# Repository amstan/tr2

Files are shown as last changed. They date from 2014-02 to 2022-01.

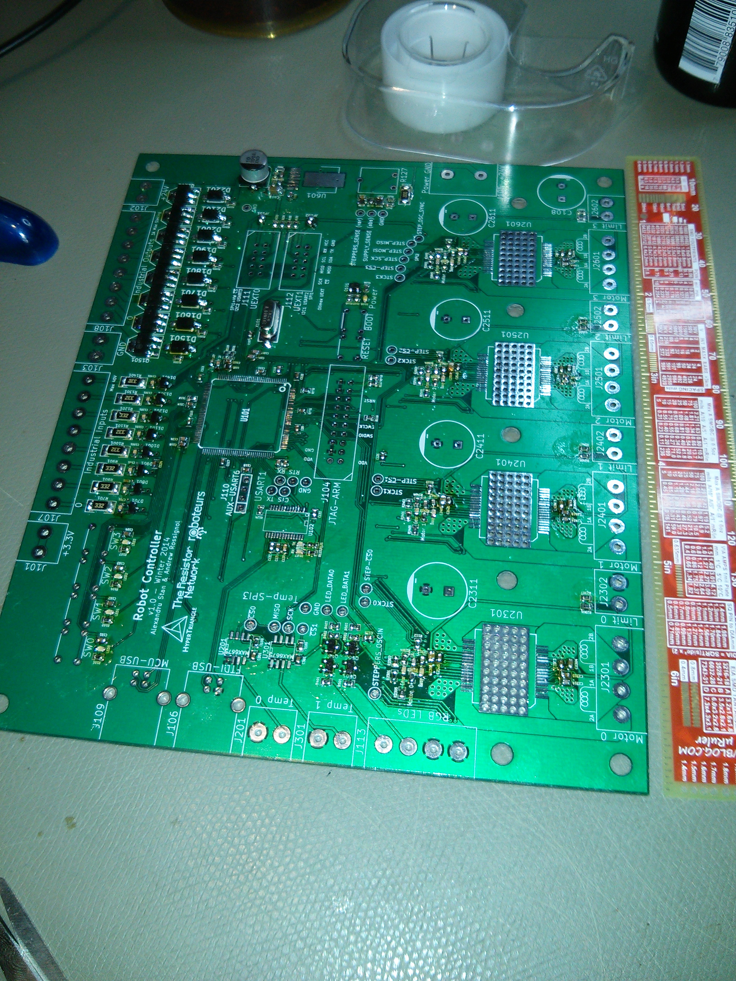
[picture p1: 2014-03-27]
pictures/board/partially assembled.jpg

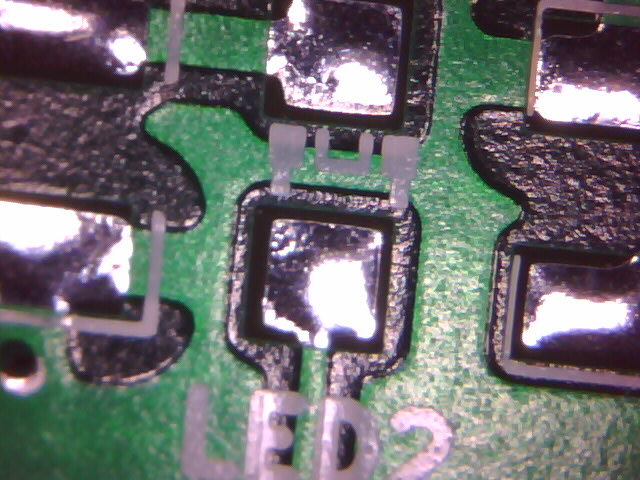
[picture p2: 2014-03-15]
pictures/board/microscope-prefab-8.jpg

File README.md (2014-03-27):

# tr2

## Overview

The goal of this project is to develop a hardware and accompanying software
platform for controlling robots from a high level programming language such as
Python.

## Hardware

The hardware will consist of a multi-axis motor control board, industrial
strength GPIO for controlling alarms, incandescent lamps, driving fans and more.

## Software

The software will provide an abstract interface to the hardware platform. The
first robot that will be tailored to this project will be a 3-axis Delta Robot.

## Project Structure

Here is the folder structure for the project:

* blender/
    * 3D models of target robots
* board/
    * The first hardware platform for this project
* board/bomParser/
    * Some pretty untested code to do mass changes in schematics/BOMs
* datasheets/
    * Component datasheets
* doc/
    * Notes, logo
* firmware/
    * Bare metal bring up of STM32F4 and code for the robot controller
* pictures/
    * Various pictures of the project
* python/
    * The python software interfaces
* ui/
    * A user interface to all of this

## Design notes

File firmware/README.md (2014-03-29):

# STM32F4 Bare Metal Bring Up

## Overview

This folder contains the base files required for the STM32F4 MCU. This work was
done on an STM32F4DISCOVERY board.

## Prerequisites

You must install the arm-none-eabi toolchain. It is available from
[this PPA](https://launchpad.net/~terry.guo/+archive/gcc-arm-embedded) for
Ubuntu/Mint.

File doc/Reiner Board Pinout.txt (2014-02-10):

STK - SPI Clock
SDL - MOSI
SDO - MISO
CS  - CS
Gnd - Gnd
Rst - Pull Up

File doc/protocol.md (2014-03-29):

# Board Protocol Definition

## Overview

This document describes the protocol used for communicating with the tr2 robot
controller board.

The tr2 robot controller board is intended merely as an IO extension of a host
platform such as a Linux Desktop PC or another embedded system.

## Message Format

    [Message Class]
    [Message Type]
    [Message Parameters]
    [CRC]

### Message Class

* Format  : Enum
* Length  : 8-bits
* Type    : MessageClass_t;
* Summary : The class of the message being sent. Example: User LED Command,
            Motor Command, Temperature Sensor Command

### Message Type

* Format  : Enum
* Length  : 8-bits
* Type    : MessageType_t (depends on the message class)
* Summary : The type of the message for this message classification. Example:
            Class: User LED Command, Type: Enable User LED

### Message Parameters

* Format  : Binary
* Length  : Variable
* Type    : uint8_t[]
* Summary : Each message class has a different set of parameters. Refer to the
            sections below for more information.

### Message Error Checking

* Format  : Binary
* Length  : 16-bits
* Type    : uint16_t
* Summary : Error checking is the last two bytes of every message. Error
            checking is a simple sum of all bytes in the message. Big-endian or
            network order is used here.

## Message Classifications

All messages communicating to and from the tr2 robot controller board have an
associated message class to aid in protocol implementation.

### User LED

* Value : 0

This classification interacts with the user LEDs on the board.

#### Message Types

##### Enable LED

* Value  : 0
* Sender : Host

This command enables one of the user LEDs.

###### Parameters

* LED Index
    * Value  : 0 - 3
    * Length : 8-bits

###### Response

Acknowledge user LED command.

##### Disable LED

* Value  : 1
* Sender : Host

This command disables one of the user LEDs.

###### Parameters

* LED Index
    * Value  : 0 - 3
    * Length : 8-bits

###### Response

Acknowledge user LED command.

##### Toggle LED

* Value  : 2
* Sender : Host

This command toggles one of the user LEDs.

###### Parameters

* LED Index
    * Value  : 0 - 3
    * Length : 8-bits

###### Response

Acknowledge user LED command.

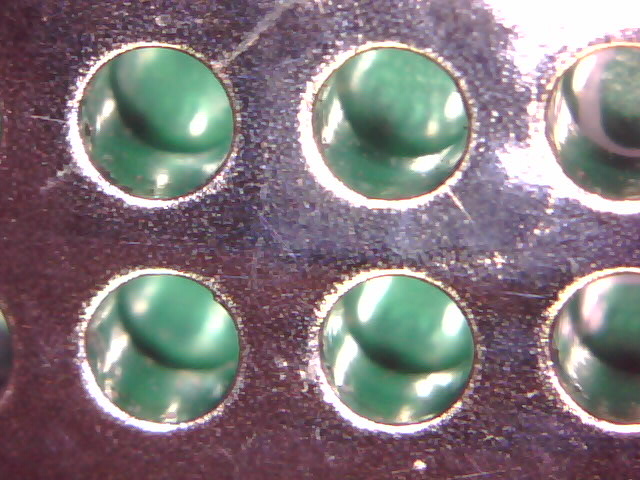
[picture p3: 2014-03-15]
pictures/board/microscope-prefab-5.jpg

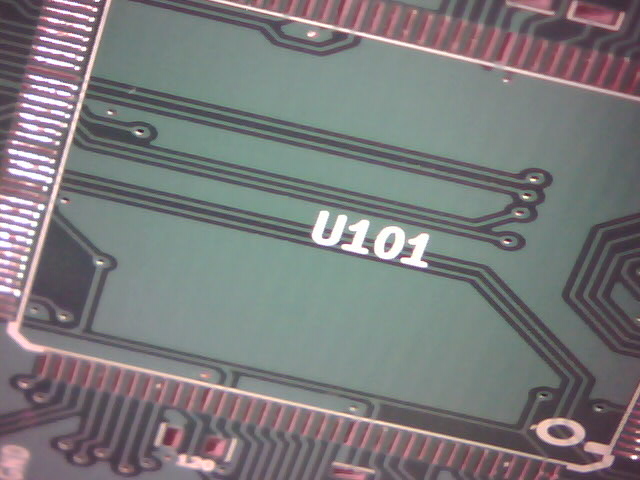
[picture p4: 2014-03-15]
pictures/board/microscope-prefab-10.jpg

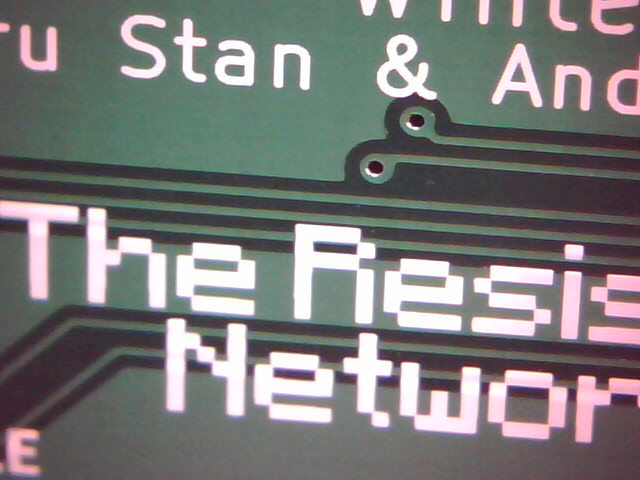
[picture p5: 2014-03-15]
pictures/board/microscope-prefab-11.jpg

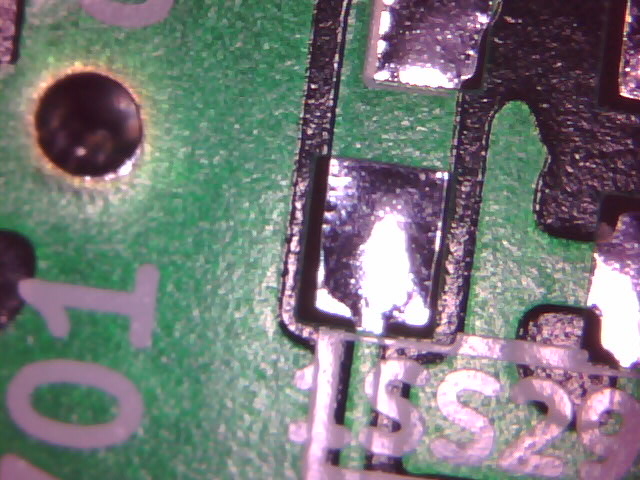
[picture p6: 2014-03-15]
pictures/board/microscope-prefab-9.jpg

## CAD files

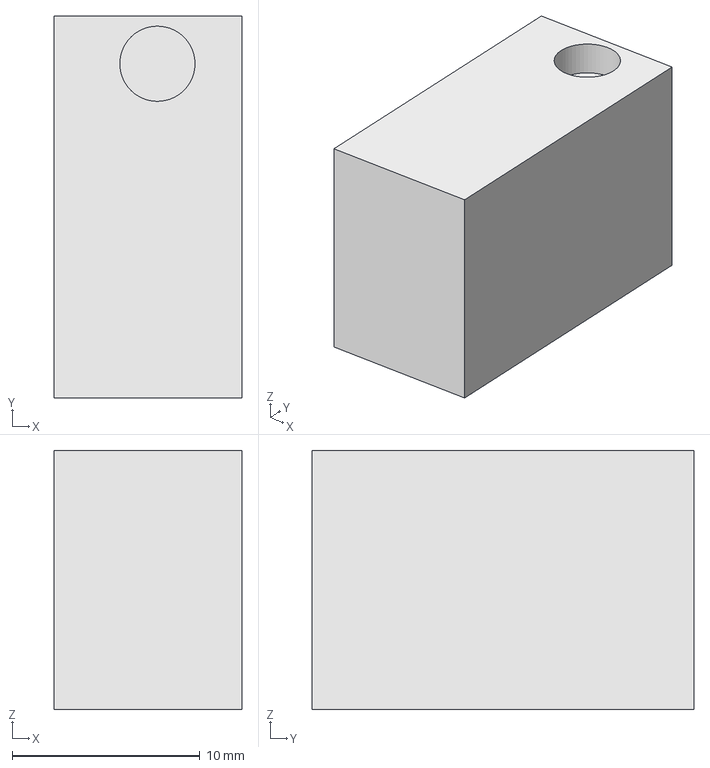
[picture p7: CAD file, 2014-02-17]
board/models/9993920000.fcstd
10.0 x 20.3 x 13.8 mm

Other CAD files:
blender/test_kinematics.blend

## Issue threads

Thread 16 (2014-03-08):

Fix connector names/values

amstan, 2014-03-08:
Kicad does not allow custom values for components from inside sheets(ex: Temp Probe connectors). I can change them inside the pcb, but every time i do another netlist import they get overwritten.

I need to name everything nicely just before the end.

Closed 2022-01-26.

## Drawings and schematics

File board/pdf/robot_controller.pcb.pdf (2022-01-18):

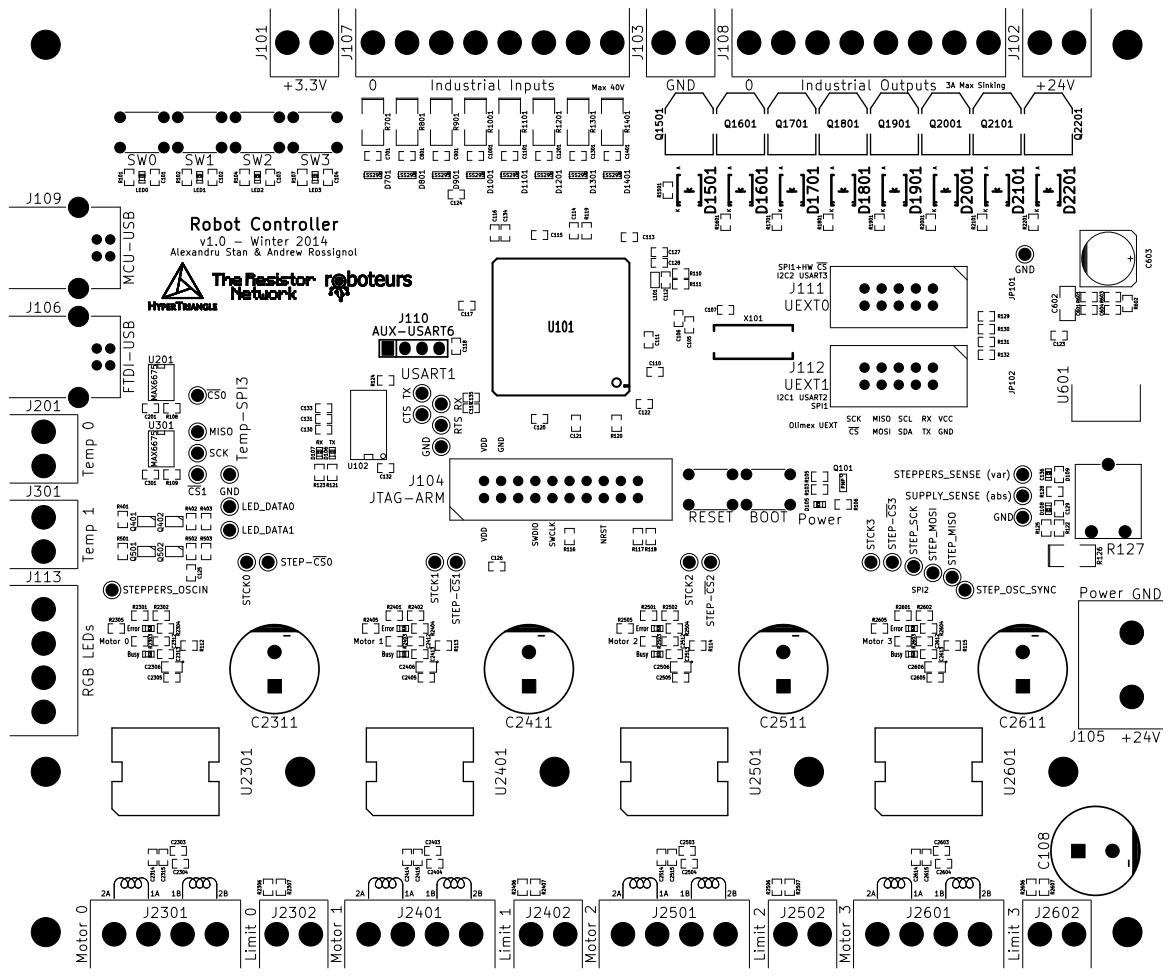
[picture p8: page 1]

Olimex UEXT Max 40V Robot Controller
J110 AUX-USART6 J2302 Limit 0

Alexandru Stan & Andrew Rossignol

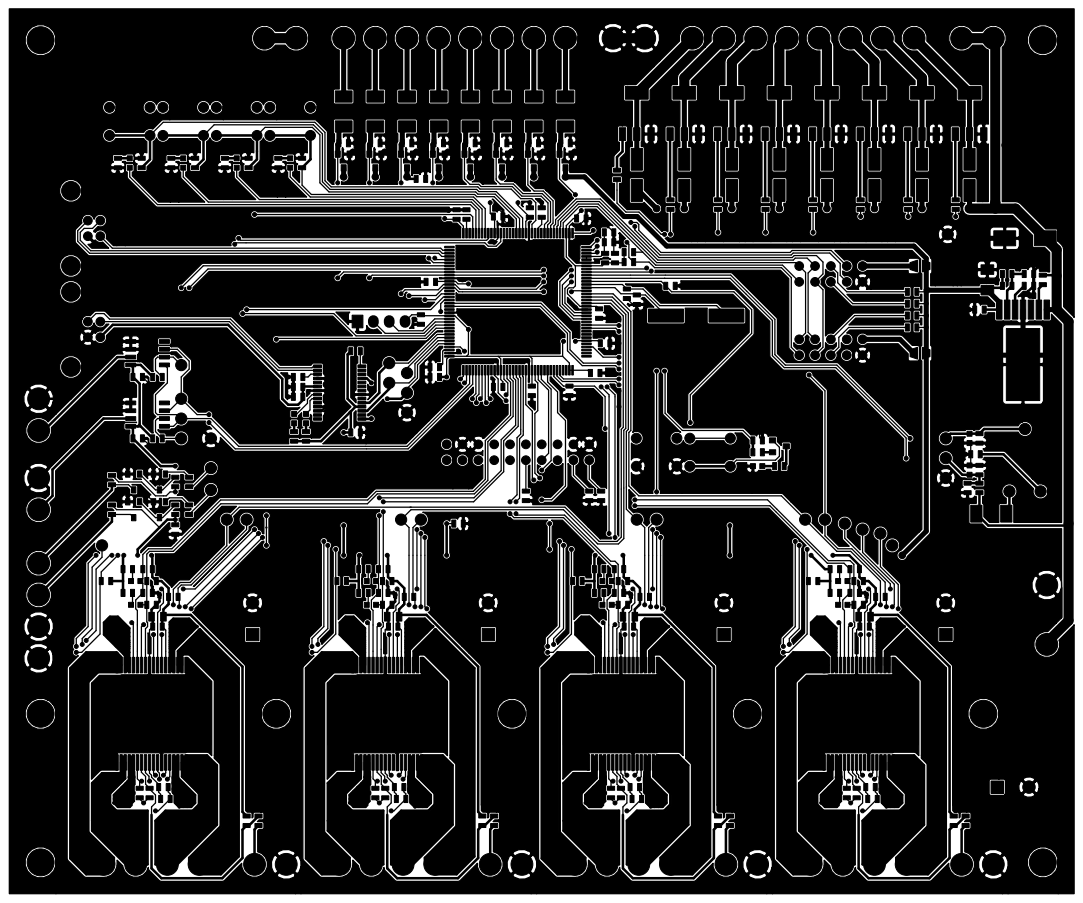
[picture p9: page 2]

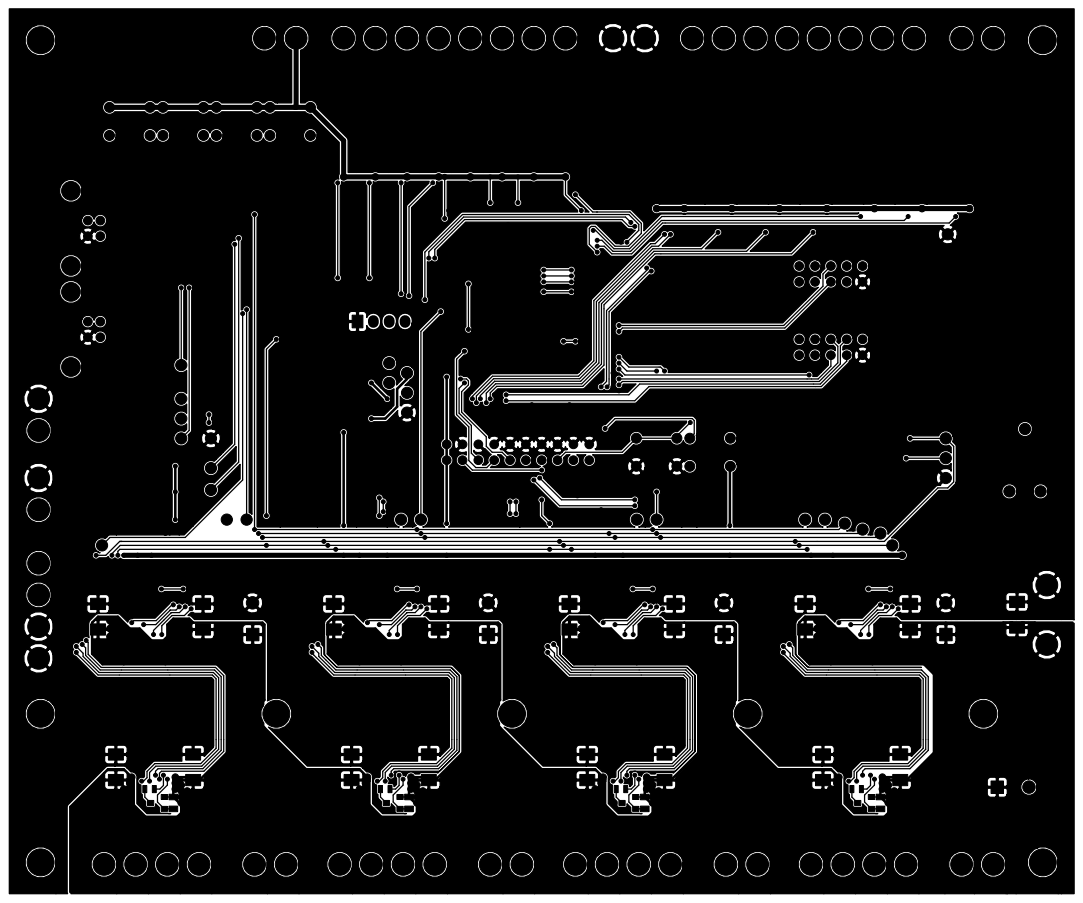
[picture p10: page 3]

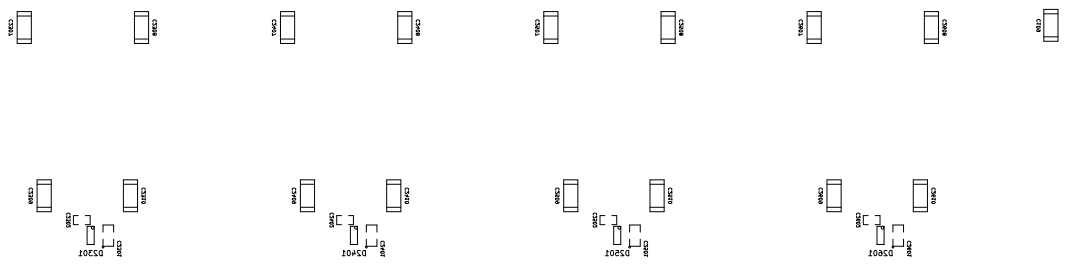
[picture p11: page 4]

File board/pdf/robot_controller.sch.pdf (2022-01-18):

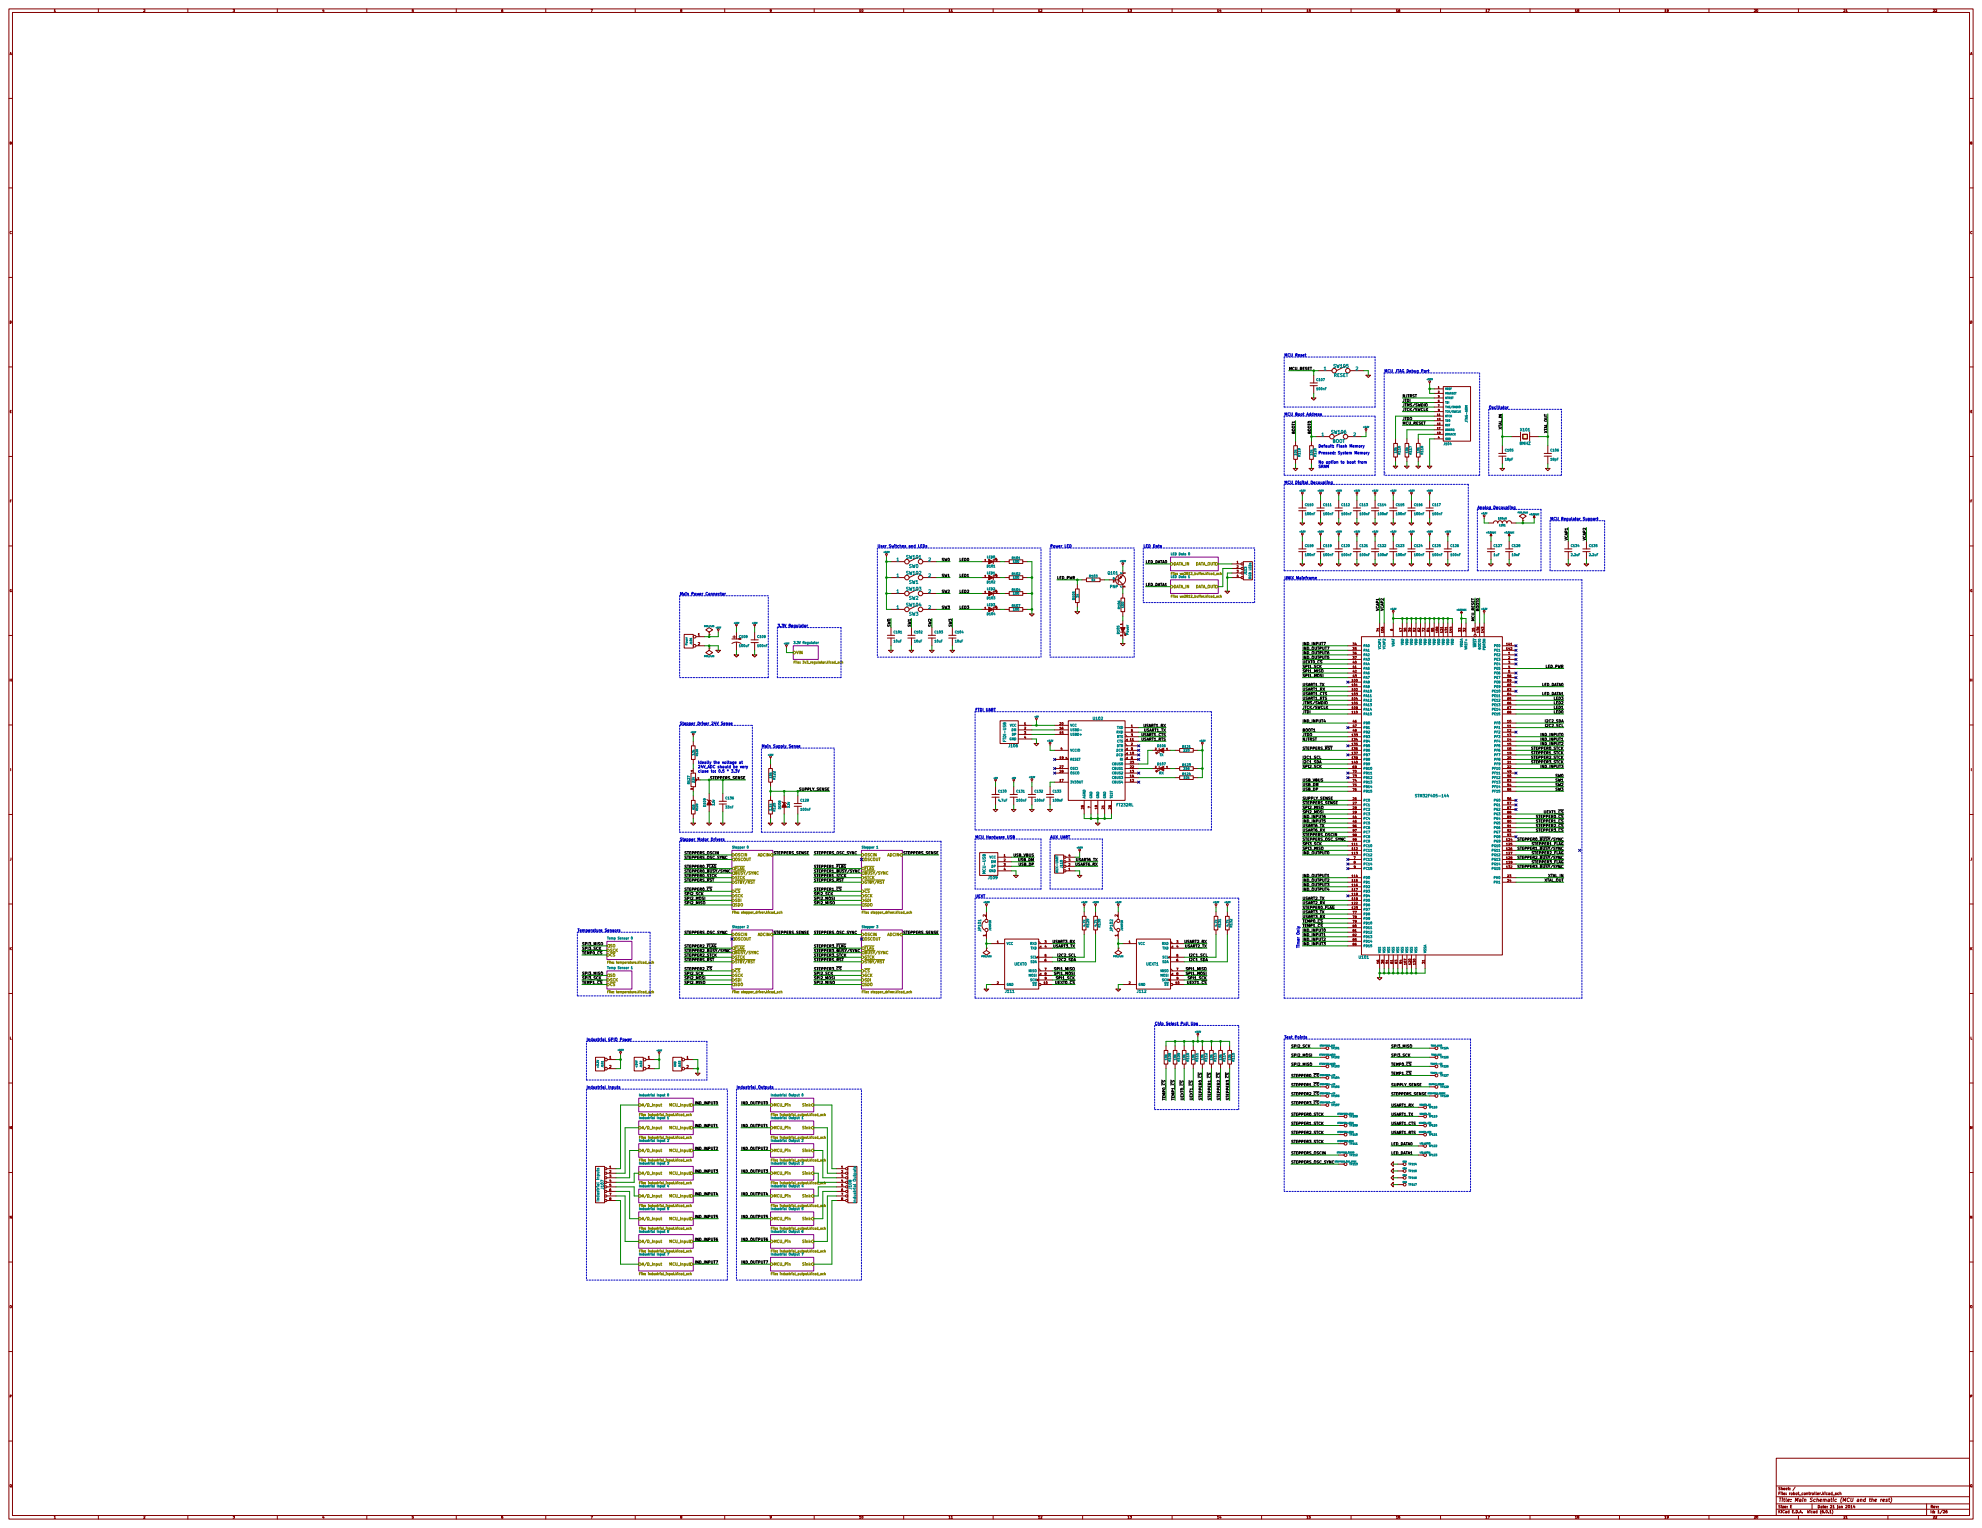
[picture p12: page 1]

MCU JTAG Debug Port Power LED

No option to boot from
SRAM

User Switches and LEDs
LED1 SW3

UNIX Mainframe Timer Only

Ideally the voltage at
24V_ADC should be very
close to: 0.5 * 3.3V
STEPPERS_SENSE

File: robot_controller.kicad_sch Sheet: /
Id: 1/26 Title: Main Schematic (MCU and the rest)

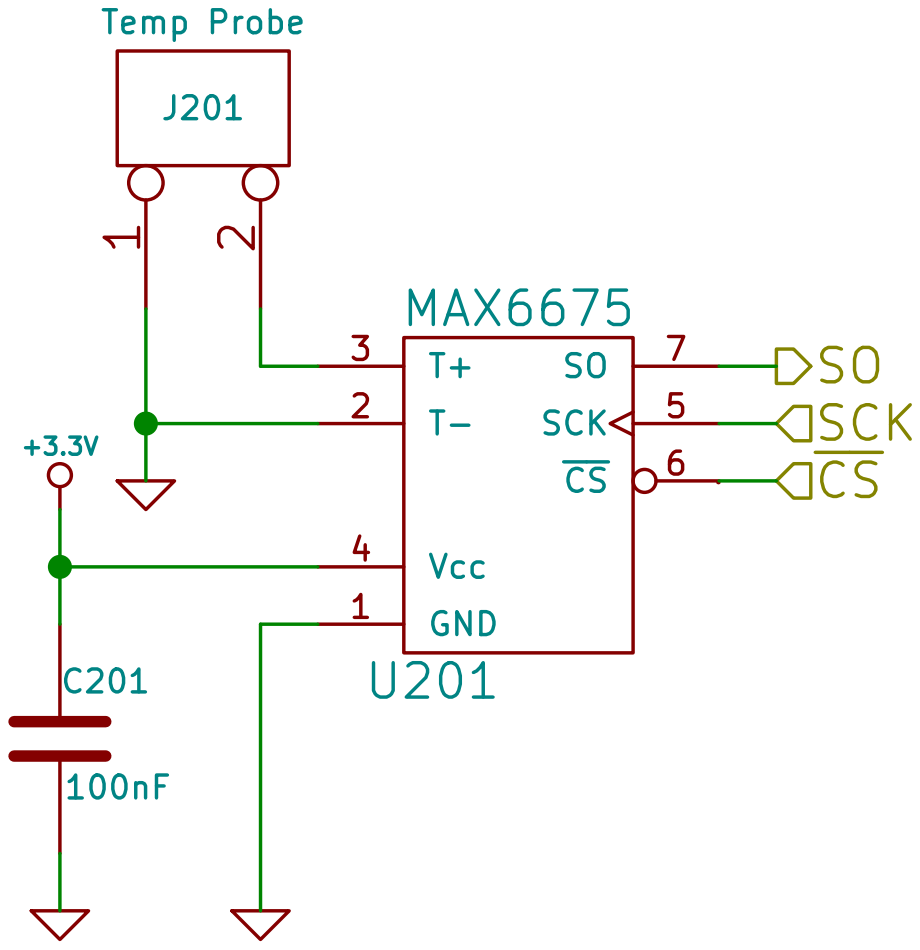
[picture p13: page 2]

Sheet: /Temp Sensor 0/
File: temperature.kicad_sch
Id: 2/26 Title: K-Type Temperature Sensor

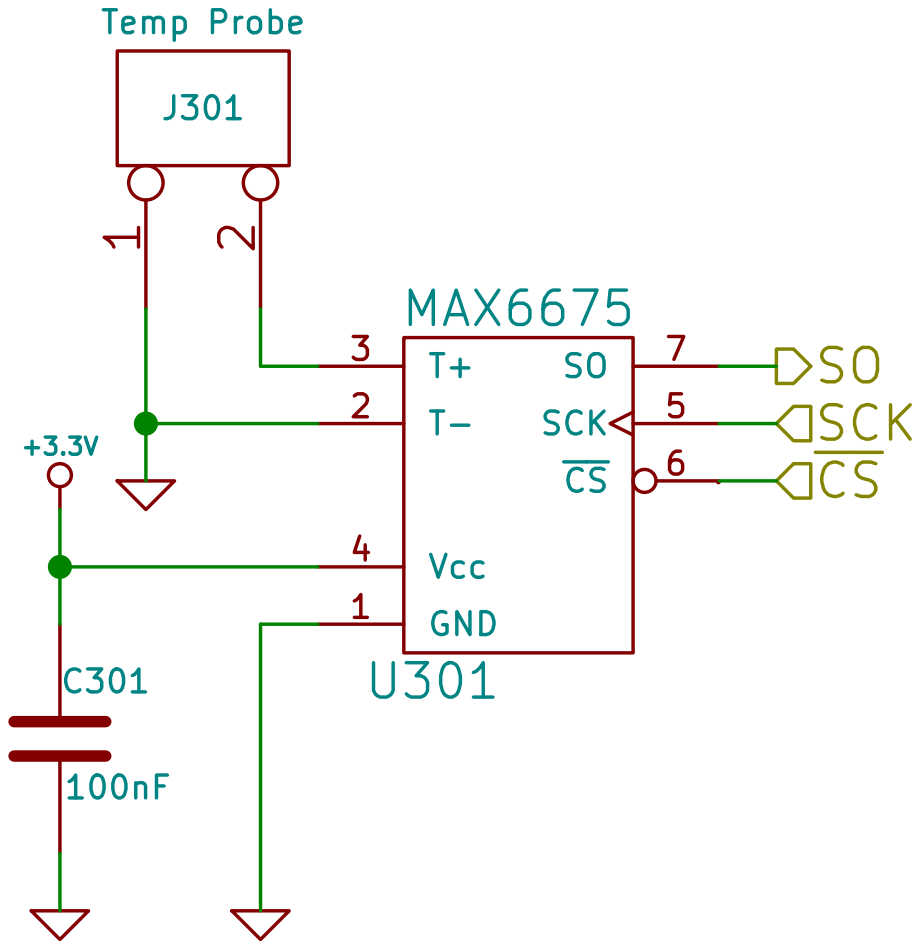
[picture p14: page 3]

Sheet: /Temp Sensor 1/
File: temperature.kicad_sch
Id: 3/26 Title: K-Type Temperature Sensor

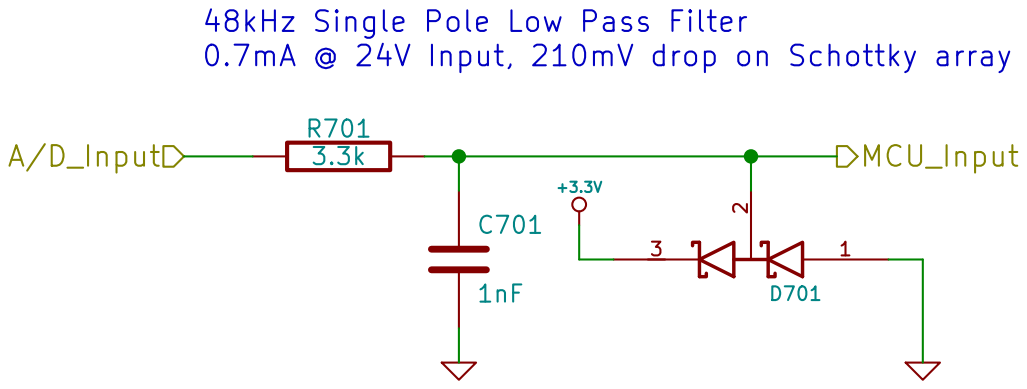
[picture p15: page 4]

48kHz Single Pole Low Pass Filter
0.7mA @ 24V Input, 210mV drop on Schottky array

Sheet: /Industrial Input 0/
File: industrial_input.kicad_sch
Id: 4/26 Title: Industrial Digital/Analog Input

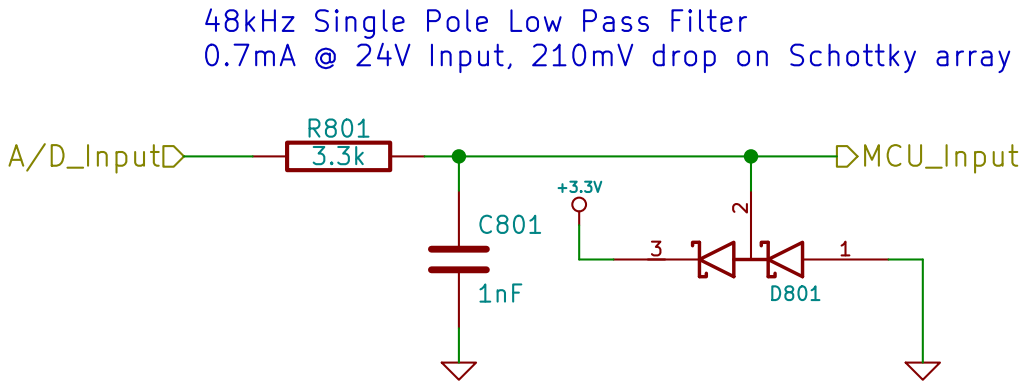
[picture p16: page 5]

48kHz Single Pole Low Pass Filter
0.7mA @ 24V Input, 210mV drop on Schottky array

Sheet: /Industrial Input 1/
File: industrial_input.kicad_sch
Id: 5/26 Title: Industrial Digital/Analog Input

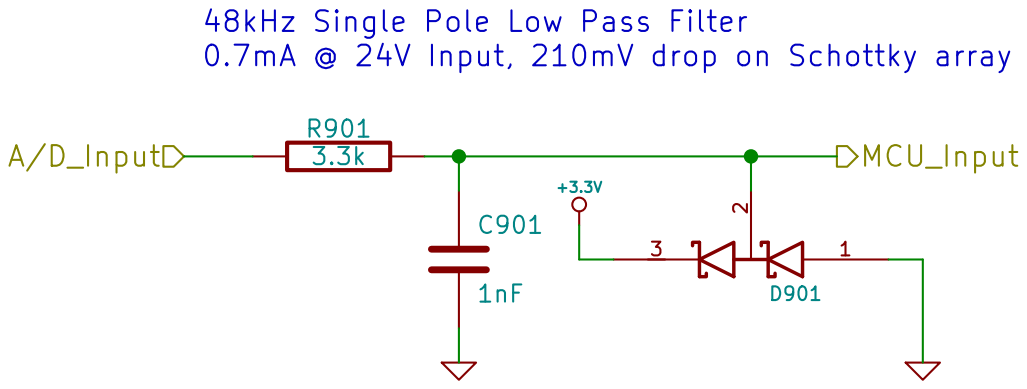
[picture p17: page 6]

48kHz Single Pole Low Pass Filter
0.7mA @ 24V Input, 210mV drop on Schottky array

Sheet: /Industrial Input 2/
File: industrial_input.kicad_sch
Id: 6/26 Title: Industrial Digital/Analog Input

48kHz Single Pole Low Pass Filter
0.7mA @ 24V Input, 210mV drop on Schottky array

Sheet: /Industrial Input 3/
File: industrial_input.kicad_sch
Id: 7/26 Title: Industrial Digital/Analog Input

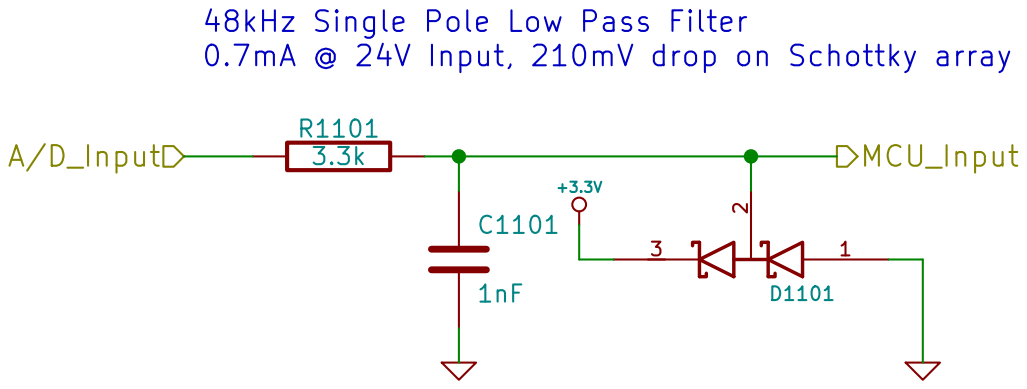
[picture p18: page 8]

48kHz Single Pole Low Pass Filter
0.7mA @ 24V Input, 210mV drop on Schottky array

Sheet: /Industrial Input 4/
File: industrial_input.kicad_sch
Id: 8/26 Title: Industrial Digital/Analog Input

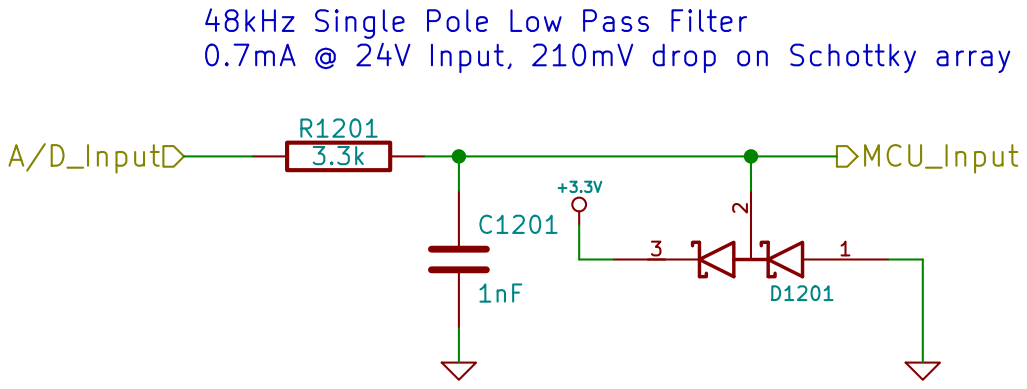
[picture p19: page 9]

48kHz Single Pole Low Pass Filter
0.7mA @ 24V Input, 210mV drop on Schottky array

Sheet: /Industrial Input 5/
File: industrial_input.kicad_sch
Id: 9/26 Title: Industrial Digital/Analog Input


48kHz Single Pole Low Pass Filter
0.7mA @ 24V Input, 210mV drop on Schottky array

Sheet: /Industrial Input 6/
File: industrial_input.kicad_sch
Id: 10/26 Title: Industrial Digital/Analog Input


48kHz Single Pole Low Pass Filter
0.7mA @ 24V Input, 210mV drop on Schottky array

Sheet: /Industrial Input 7/
File: industrial_input.kicad_sch
Id: 11/26 Title: Industrial Digital/Analog Input


1 2 Busy D2303 SPI PGND 1 OSCIN 10 OSCOUT 11 AGND 12 CP 13 VBOOT 14 VSB 15 OUT1B 17 OUT1A 2 OUT2B 20 VDD 24 SDO 25 SCK 26 SDI 27 DGND 28

4 ~{STBY/RST} 6 SW 7 ADCIN 8 VREG

File: stepper_driver.kicad_sch
Id: 12/26 Title: L64470 Stepper Driver


1 2 Busy D2403 SPI PGND 1 OSCIN 10 OSCOUT 11 AGND 12 CP 13 VBOOT 14 VSB 15 OUT1B 17 OUT1A 2 OUT2B 20 VDD 24 SDO 25 SCK 26 SDI 27 DGND 28

4 ~{STBY/RST} 6 SW 7 ADCIN 8 VREG

File: stepper_driver.kicad_sch
Id: 23/26 Title: L64470 Stepper Driver


1 2 Busy D2503 SPI PGND 1 OSCIN 10 OSCOUT 11 AGND 12 CP 13 VBOOT 14 VSB 15 OUT1B 17 OUT1A 2 OUT2B 20 VDD 24 SDO 25 SCK 26 SDI 27 DGND 28

4 ~{STBY/RST} 6 SW 7 ADCIN 8 VREG

File: stepper_driver.kicad_sch
Id: 13/26 Title: L64470 Stepper Driver


1 2 Busy D2603 SPI PGND 1 OSCIN 10 OSCOUT 11 AGND 12 CP 13 VBOOT 14 VSB 15 OUT1B 17 OUT1A 2 OUT2B 20 VDD 24 SDO 25 SCK 26 SDI 27 DGND 28

4 ~{STBY/RST} 6 SW 7 ADCIN 8 VREG

File: stepper_driver.kicad_sch
Id: 24/26 Title: L64470 Stepper Driver


Sheet: /Industrial Output 0/
File: industrial_output.kicad_sch
Id: 14/26 Title: Industrial Digital Output


Sheet: /Industrial Output 1/
File: industrial_output.kicad_sch
Id: 15/26 Title: Industrial Digital Output


Sheet: /Industrial Output 2/
File: industrial_output.kicad_sch
Id: 16/26 Title: Industrial Digital Output


Sheet: /Industrial Output 3/
File: industrial_output.kicad_sch
Id: 17/26 Title: Industrial Digital Output


Sheet: /Industrial Output 4/
File: industrial_output.kicad_sch
Id: 18/26 Title: Industrial Digital Output


Sheet: /Industrial Output 5/
File: industrial_output.kicad_sch
Id: 19/26 Title: Industrial Digital Output

Sheet: /Industrial Output 6/
File: industrial_output.kicad_sch
Id: 20/26 Title: Industrial Digital Output


Sheet: /Industrial Output 7/
File: industrial_output.kicad_sch
Id: 21/26 Title: Industrial Digital Output


File: 3v3_regulator.kicad_sch
Id: 22/26 Title: 3.3V Switching Regulator

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

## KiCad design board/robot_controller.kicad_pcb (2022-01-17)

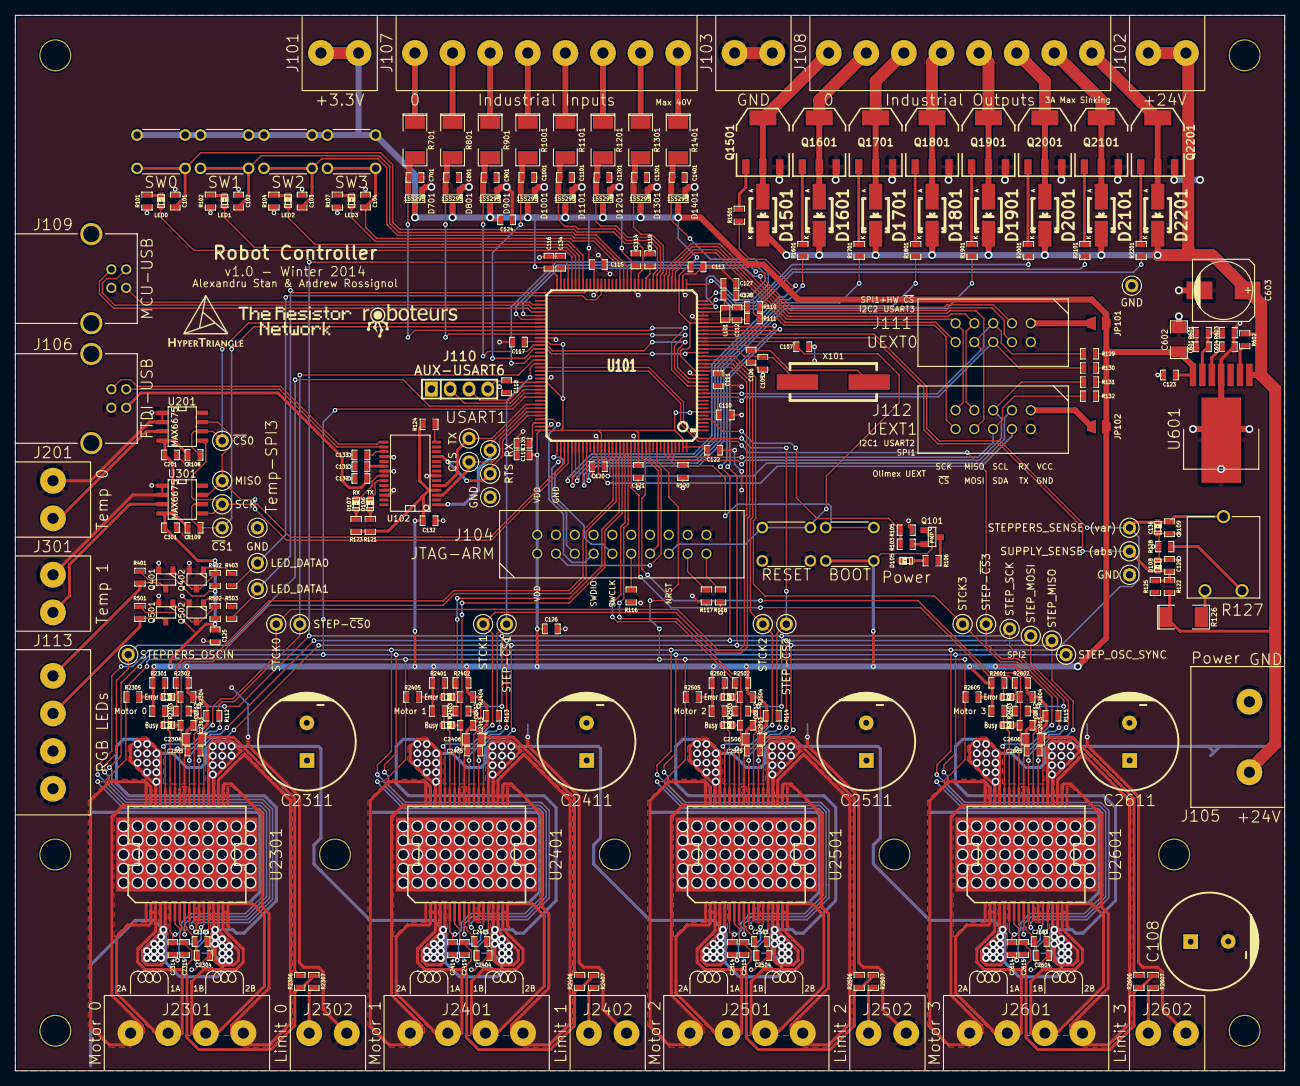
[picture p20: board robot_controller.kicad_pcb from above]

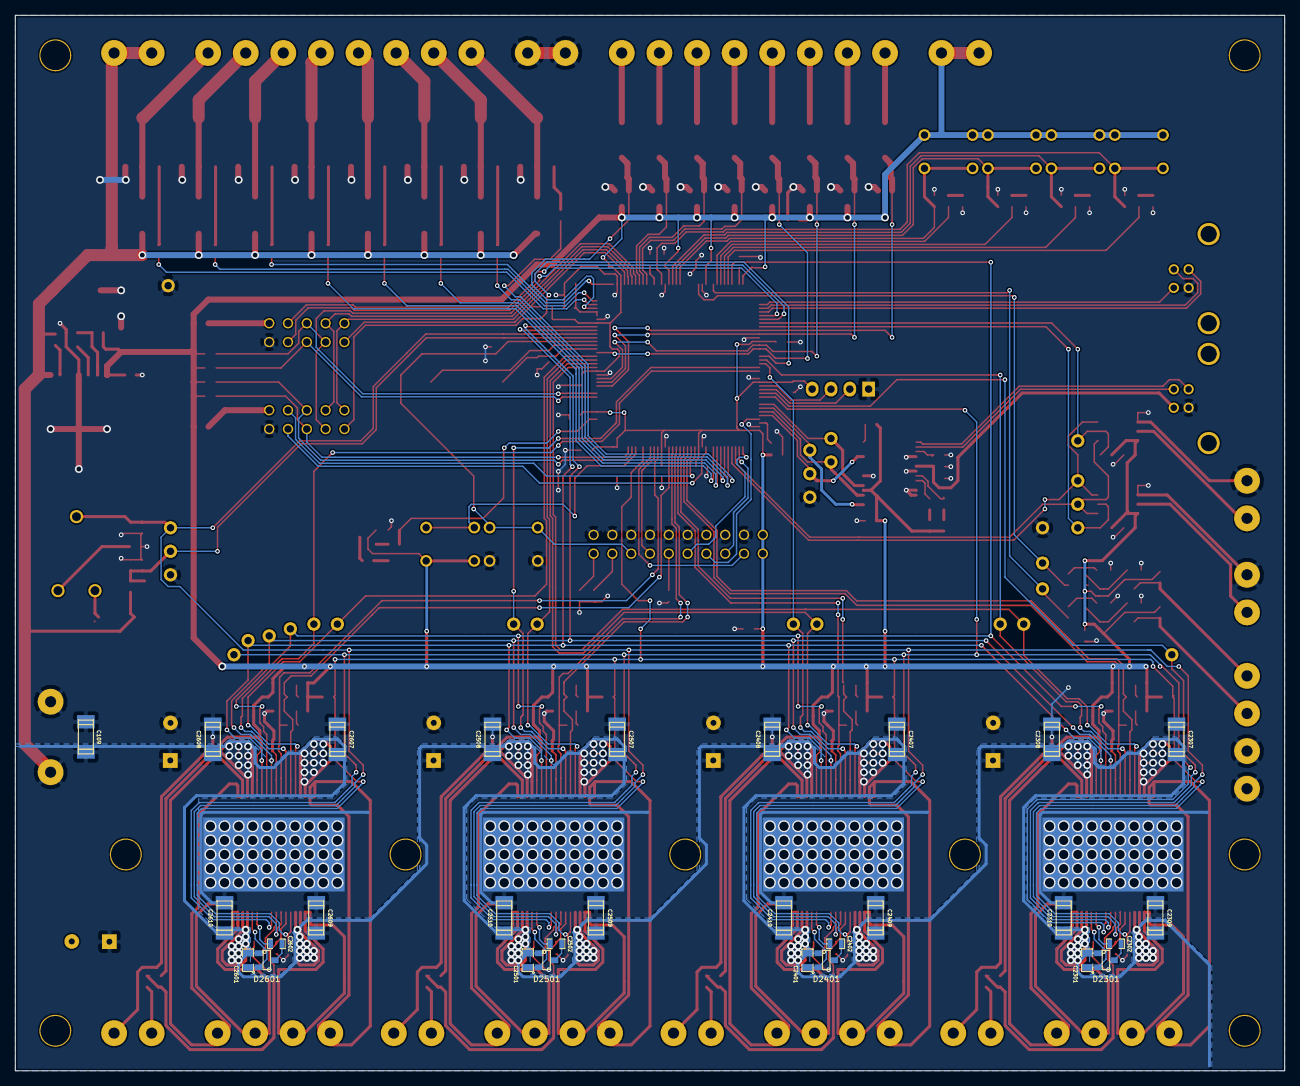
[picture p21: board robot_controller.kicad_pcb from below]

Board: 2 copper layers, 171.4 x 142.6 mm, 325 parts (29 on the bottom side), 199 nets.

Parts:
C101, C102, C103, C104, C2304, C2404, C2504, C2604: 10uF; SM0603_Capa
C105, C106: 18pF; SM0603_Capa
C107, C110, C111, C112, C113, C114, C115, C116, C117, C118, C119, C120, C121, C122, C123, C124, C125, C126, C129, C131, C132, C133, C201, C301, C2303, C2305, C2315, C2403, C2405, C2415, C2503, C2505, C2515, C2603, C2605, C2615: 100nF; SM0603_Capa
C108, C2311, C2411, C2511, C2611: 100uF; CP_13x21mm
C109, C2307, C2308, C2309, C2310, C2407, C2408, C2409, C2410, C2507, C2508, C2509, C2510, C2607, C2608, C2609, C2610: 100nF; c_1808
C127: 1uF; SM0603_Capa
C128, C2302, C2402, C2502, C2602: 10nF; SM0603_Capa
C130: 4.7uF; SM0603_Capa
C134, C135: 2.2uF; SM0603_Capa
C136: 33nF; SM0603_Capa
C601, C604: 22nF; SM0603_Capa
C602: 100uF; SM1206
C603: 10uF; c_elec_8x10
C701, C801, C901, C1001, C1101, C1201, C1301, C1401: 1nF; SM0603_Capa
C2301, C2401, C2501, C2601: 220nF; SM0805
C2306, C2406, C2506, C2606: 47uF; SM0805
C2312, C2313, C2314, C2412, C2413, C2414, C2512, C2513, C2514, C2612, C2613, C2614: 100pF; SM0603_Capa
D101: LED0; LED-0603
D102: LED1; LED-0603
D103: LED2; LED-0603
D104: LED3; LED-0603
D105: Power; LED-0603
D106: TX; LED-0603
D107: RX; LED-0603
D108, D109: 3.3V; LED-0603
D701, D801, D901, D1001, D1101, D1201, D1301, D1401: 1SS295; SOT23-EXTRASPECIAL
D1501, D1601, D1701, D1801, D1901, D2001, D2101, D2201: RSX501L-20TE25; Diode-SMA_Handsoldering
D2301, D2401, D2501, D2601: DOUBLE_SCHOTTKY; SOT23-SPECIAL
D2302, D2402, D2502, D2602: Error; LED-0603
D2303, D2403, D2503, D2603: Busy; LED-0603
J101: +3.3V; SCONN_2
J102: +24V; SCONN_2
J103: GND; SCONN_2
J104: JTAG-ARM; SHROUDED_20
J105: Power; PWRSCONN_2
J106: FTDI-USB; USB_B
J107: Industrial Inputs; SCONN_8
J108: Industrial Outputs; SCONN_8
J109: MCU-USB; USB_B
J110: AUX-USART6; Pin_Header_Straight_1x04
J111: UEXT0; SHROUDED_10
J112: UEXT1; SHROUDED_10
J113: RGB LEDs; SCONN_4
J201: Temp 0; SCONN_2
J301: Temp 1; SCONN_2
J2301: Motor 0; CONN_STEPPER
J2302: Limit 0; SCONN_2
J2401: Motor 1; CONN_STEPPER
J2402: Limit 1; SCONN_2
J2501: Motor 2; CONN_STEPPER
J2502: Limit 2; SCONN_2
J2601: Motor 3; CONN_STEPPER
J2602: Limit 3; SCONN_2
JP101, JP102: JUMPER; SOLDER_BRIDGE
L101: 100uH; SM0603
MH: MountingHole_2-5mm_RevA_Date21Jun2010; MountingHole_4mm
MH#2, MH#3, MH#4, MH#5, MH#6, MH#7, MH#8, MH#9: MountingHole_2-5mm_RevA_Date21Jun2010; MountingHole_4mm
Q101: PNP; SOT23-EXTRASPECIAL
Q401, Q402, Q501, Q502: MMBT5962; SOT23_INV
Q1501, Q1601, Q1701, Q1801, Q1901, Q2001, Q2101, Q2201: NJT4031NT1G; SOT223-EXTRASPECIAL
R101, R102, R104, R106, R107, R2307, R2407, R2507, R2607: 100; SM0603_Resistor
R103, R105, R402, R403, R502, R503: 1k; SM0603_Resistor
R108, R109, R110, R111, R112, R113, R114, R115, R116, R117, R118, R119, R120, R124, R2306, R2406, R2506, R2606: 10k; SM0603_Resistor
R121, R2303, R2403, R2503, R2603: 220; SM0603_Resistor
R122: 15k; SM0603_Resistor
R123, R2301, R2401, R2501, R2601: 316; SM0603_Resistor
R125, R603: 1.1k; SM0603_Resistor
R126, R701, R801, R901, R1001, R1101, R1201, R1301, R1401: 3.3k; SM2010
R127: 22k; TRIMMER_POT
R128: 820; SM0603_Resistor
R129, R130, R131, R132: 4.7k; SM0603_Resistor
R401, R501: 200; SM0603_Resistor
R601: 3.3k; SM0603_Resistor
R602: 62k; SM0603_Resistor
R1501, R1601, R1701, R1801, R1901, R2001, R2101, R2201: 470; SM0603_Resistor
R2302, R2304, R2305, R2402, R2404, R2405, R2502, R2504, R2505, R2602, R2604, R2605: 39k; SM0603_Resistor
SW101: SW0; PB
SW102: SW1; PB
SW103: SW2; PB
SW104: SW3; PB
SW105: RESET; PB
SW106: BOOT; PB
TP101: STEP_SCK; MINI_TP
TP102: STEP_MOSI; MINI_TP
TP103: STEP_MISO; MINI_TP
TP104: STEP-~{CS}0; MINI_TP
TP105: STEP-~{CS}1; MINI_TP
TP106: STEP-~{CS}2; MINI_TP
TP107: STEP-~{CS}3; MINI_TP
TP108: STCK0; MINI_TP
TP109: STCK1; MINI_TP
TP110: STCK2; MINI_TP
TP111: STCK3; MINI_TP
TP112: STEPPERS_OSCIN; MINI_TP
TP113: STEP_OSC_SYNC; MINI_TP
TP114, TP115, TP116, TP117: GND; MINI_TP
TP118: RX; MINI_TP
TP119: TX; MINI_TP
TP120: CTS; MINI_TP
TP121: RTS; MINI_TP
TP122: LED_DATA0; MINI_TP
TP123: LED_DATA1; MINI_TP
TP124: MISO; MINI_TP
TP125: SCK; MINI_TP
TP126: ~{CS}0; MINI_TP
TP127: ~{CS}1; MINI_TP
TP128: SUPPLY_SENSE (abs); MINI_TP
TP129: STEPPERS_SENSE (var); MINI_TP
U101: STM32F405-144; TQFP144
U102: FT232RL; SSOP-28
U201, U301: MAX6675; SOIC-8_N
U601: LMZ14201; PFM7
U2301, U2401, U2501, U2601: L6470; POWERSO-36
X101: 8MHZ; Crystal_HC49-SD_SMD

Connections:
+3.3V: C110.1, C111.1, C112.1, C113.1, C114.1, C115.1, C116.1, C117.1, C118.1, C119.1, C120.1, C121.1, C122.1, C123.1, C124.1, C125.1, C126.1, C132.1, C201.1, C301.1, C601.1, C602.1, C2305.1, C2306.1, C2405.1, C2406.1, C2505.1, C2506.1, C2605.1, C2606.1, D701.3, D801.3, D901.3, D1001.3, D1101.3, D1201.3, D1301.3, D1401.3, J101.1, J101.2, J104.1, J104.2, J110.4, JP101.2, JP102.2, L101.1, Q101.1, R108.1, R109.1, R110.1, R111.1, R112.1, R113.1, R114.1, R115.1, R121.2, R123.2, R124.2, R129.1, R130.1, R131.1, R132.1, R401.1, R402.1, R501.1, R502.1, R601.1, R2301.1, R2302.1, R2303.1, R2304.1, R2305.1, R2306.1, R2401.1, R2402.1, R2403.1, R2404.1, R2405.1, R2406.1, R2501.1, R2502.1, R2503.1, R2504.1, R2505.1, R2506.1, R2601.1, R2602.1, R2603.1, R2604.1, R2605.1, R2606.1, SW101.1, SW102.1, SW103.1, SW104.1, SW106.2, U101.6, U101.17, U101.30, U101.39, U101.52, U101.62, U101.72, U101.84, U101.95, U101.108, U101.121, U101.131, U101.143, U101.144, U102.4, U201.4, U301.4, U601.7, U2301.24, U2401.24, U2501.24, U2601.24
+3.3VADC: C127.1, C128.1, L101.2, U101.32, U101.33
+5V: C130.1, C131.1, J106.1, U102.20
+24V: C108.1, C109.1, C603.1, C2301.2, C2307.1, C2308.1, C2309.1, C2310.1, C2311.1, C2401.2, C2407.1, C2408.1, C2409.1, C2410.1, C2411.1, C2501.2, C2507.1, C2508.1, C2509.1, C2510.1, C2511.1, C2601.2, C2607.1, C2608.1, C2609.1, C2610.1, C2611.1, D1501.2, D1601.2, D1701.2, D1801.2, D1901.2, D2001.2, D2101.2, D2201.2, D2301.1, D2401.1, D2501.1, D2601.1, J102.1, J102.2, J105.1, R122.1, R126.1, R602.1, U601.1, U2301.4, U2301.5, U2301.15, U2301.16, U2301.22, U2301.23, U2301.33, U2301.34, U2401.4, U2401.5, U2401.15, U2401.16, U2401.22, U2401.23, U2401.33, U2401.34, U2501.4, U2501.5, U2501.15, U2501.16, U2501.22, U2501.23, U2501.33, U2501.34, U2601.4, U2601.5, U2601.15, U2601.16, U2601.22, U2601.23, U2601.33, U2601.34
/BOOT0: R120.1, SW106.1, U101.138
/BOOT1: R119.1, U101.48
/I2C1_SCL: J112.5, R131.2, U101.139
/I2C1_SDA: J112.6, R132.2, U101.140
/I2C2_SCL: J111.5, R129.2, U101.11
/I2C2_SDA: J111.6, R130.2, U101.10
/Industrial Input 0/A/D_Input: J107.1, R701.1
/Industrial Input 0/MCU_Input: C701.1, D701.2, R701.2, U101.13, U101.81
/Industrial Input 1/A/D_Input: J107.2, R801.1
/Industrial Input 1/MCU_Input: C801.1, D801.2, R801.2, U101.14, U101.82
/Industrial Input 2/A/D_Input: J107.3, R901.1
/Industrial Input 2/MCU_Input: C901.1, D901.2, R901.2, U101.15, U101.85
/Industrial Input 3/A/D_Input: J107.4, R1001.1
/Industrial Input 3/MCU_Input: C1001.1, D1001.2, R1001.2, U101.22, U101.86
/Industrial Input 4/A/D_Input: J107.5, R1101.1
/Industrial Input 4/MCU_Input: C1101.1, D1101.2, R1101.2, U101.46
/Industrial Input 5/A/D_Input: J107.6, R1201.1
/Industrial Input 5/MCU_Input: C1201.1, D1201.2, R1201.2, U101.45
/Industrial Input 6/A/D_Input: J107.7, R1301.1
/Industrial Input 6/MCU_Input: C1301.1, D1301.2, R1301.2, U101.44
/Industrial Input 7/A/D_Input: J107.8, R1401.1
/Industrial Input 7/MCU_Input: C1401.1, D1401.2, R1401.2, U101.34
/Industrial Output 0/MCU_Pin: R1501.1, U101.113
/Industrial Output 0/Sink: D1501.1, J108.1, Q1501.3
/Industrial Output 1/MCU_Pin: R1601.1, U101.114
/Industrial Output 1/Sink: D1601.1, J108.2, Q1601.3
/Industrial Output 2/MCU_Pin: R1701.1, U101.115
/Industrial Output 2/Sink: D1701.1, J108.3, Q1701.3
/Industrial Output 3/MCU_Pin: R1801.1, U101.116
/Industrial Output 3/Sink: D1801.1, J108.4, Q1801.3
/Industrial Output 4/MCU_Pin: R1901.1, U101.117
/Industrial Output 4/Sink: D1901.1, J108.5, Q1901.3
/Industrial Output 5/MCU_Pin: R2001.1, U101.37
/Industrial Output 5/Sink: D2001.1, J108.6, Q2001.3
/Industrial Output 6/MCU_Pin: R2101.1, U101.36
/Industrial Output 6/Sink: D2101.1, J108.7, Q2101.3
/Industrial Output 7/MCU_Pin: R2201.1, U101.35
/Industrial Output 7/Sink: D2201.1, J108.8, Q2201.3
/JTCK/SWCLK: J104.9, U101.109
/JTDI: J104.5, U101.110
/JTDO: J104.13, U101.133
/JTMS/SWDIO: J104.7, U101.105
/LED0: D101.1, U101.68
/LED1: D102.1, U101.67
/LED2: D103.1, U101.66
/LED3: D104.1, U101.65
/LED Data 0/DATA_IN: R403.2, TP122.1, U101.60
/LED Data 0/DATA_OUT: J113.1, Q401.3, R401.2
/LED Data 1/DATA_IN: R503.2, TP123.1, U101.64
/LED Data 1/DATA_OUT: J113.2, Q501.3, R501.2
/LED_PWR: R103.1, R105.2, U101.4
/MCU_RESET: C107.1, J104.15, SW105.1, U101.25
/NJTRST: J104.3, U101.134
/SPI1_MISO: J111.7, J112.7, U101.42
/SPI1_MOSI: J111.8, J112.8, U101.43
/SPI1_SCK: J111.9, J112.9, U101.41
/SUPPLY_SENSE: C129.1, D108.2, R122.2, R125.1, TP128.1, U101.26
/SW0: C101.1, SW101.2, U101.50
/SW1: C102.1, SW102.2, U101.53
/SW2: C103.1, SW103.2, U101.54
/SW3: C104.1, SW104.2, U101.55
/Stepper 0/ADCIN: C136.1, D109.2, R127.2, TP129.1, U101.27, U2301.8, U2401.8, U2501.8, U2601.8
/Stepper 0/OSCIN: TP112.1, U101.98, U2301.10
/Stepper 0/SCK: TP101.1, U101.69, U2301.26, U2401.26, U2501.26, U2601.26
/Stepper 0/SDI: TP102.1, U101.29, U2301.27, U2401.27, U2501.27, U2601.27
/Stepper 0/SDO: TP103.1, U101.28, U2301.25, U2401.25, U2501.25, U2601.25
/Stepper 0/STCK: TP108.1, U101.18, U2301.32
/Stepper 0/VREG: C2303.1, C2304.1, U2301.9
/Stepper 0/~BUSY/SYNC: C2313.1, D2303.2, R2304.2, U101.124, U2301.29
/Stepper 0/~CS: R112.2, TP104.1, U101.89, U2301.30
/Stepper 0/~FLAG: C2312.1, D2302.2, R2302.2, U101.123, U2301.31
/Stepper 0/~STBY/RST: C2314.1, C2414.1, C2514.1, C2614.1, R2305.2, R2405.2, R2505.2, R2605.2, U101.136, U2301.6, U2401.6, U2501.6, U2601.6
/Stepper 1/OSCIN: TP113.1, U101.99, U2301.11, U2401.10, U2501.10, U2601.10
/Stepper 1/STCK: TP109.1, U101.19, U2401.32
/Stepper 1/VREG: C2403.1, C2404.1, U2401.9
/Stepper 1/~BUSY/SYNC: C2413.1, D2403.2, R2404.2, U101.126, U2401.29
/Stepper 1/~CS: R113.2, TP105.1, U101.90, U2401.30
/Stepper 1/~FLAG: C2412.1, D2402.2, R2402.2, U101.125, U2401.31
/Stepper 2/STCK: TP110.1, U101.20, U2501.32
/Stepper 2/VREG: C2503.1, C2504.1, U2501.9
/Stepper 2/~BUSY/SYNC: C2513.1, D2503.2, R2504.2, U101.128, U2501.29
/Stepper 2/~CS: R114.2, TP106.1, U101.91, U2501.30
/Stepper 2/~FLAG: C2512.1, D2502.2, R2502.2, U101.127, U2501.31
/Stepper 3/STCK: TP111.1, U101.21, U2601.32
/Stepper 3/VREG: C2603.1, C2604.1, U2601.9
/Stepper 3/~BUSY/SYNC: C2613.1, D2603.2, R2604.2, U101.132, U2601.29
/Stepper 3/~CS: R115.2, TP107.1, U101.92, U2601.30
/Stepper 3/~FLAG: C2612.1, D2602.2, R2602.2, U101.129, U2601.31
/Temp Sensor 0/SCK: TP125.1, U101.111, U201.5, U301.5
/Temp Sensor 0/SO: TP124.1, U101.112, U201.7, U301.7
/Temp Sensor 0/~CS: R108.2, TP126.1, U101.79, U201.6
/Temp Sensor 1/~CS: R109.2, TP127.1, U101.80, U301.6
/UEXT0_~CS: J111.10, R110.2, U101.40
/UEXT1_~CS: J112.10, R111.2, U101.88
/USART1_CTS: TP120.1, U101.103, U102.3
/USART1_RTS: TP121.1, U101.104, U102.11
/USART1_RX: TP118.1, U101.102, U102.1
/USART1_TX: TP119.1, U101.101, U102.5
/USART2_RX: J112.3, U101.122
/USART2_TX: J112.4, U101.119
/USART3_RX: J111.3, U101.78
/USART3_TX: J111.4, U101.77
/USART6_RX: J110.2, U101.97
/USART6_TX: J110.3, U101.96
/USB_DM: J109.2, U101.75
/USB_DP: J109.3, U101.76
/USB_VBUS: J109.1, U101.74
/VCAP1: C134.1, U101.71
/VCAP2: C135.1, U101.106
/XTAL_IN: C105.1, U101.23, X101.1
/XTAL_OUT: C106.1, U101.24, X101.2
GND: C101.2, C102.2, C103.2, C104.2, C105.2, C106.2, C107.2, C108.2, C109.2, C110.2, C111.2, C112.2, C113.2, C114.2, C115.2, C116.2, C117.2, C118.2, C119.2, C120.2, C121.2, C122.2, C123.2, C124.2, C125.2, C126.2, C127.2, C128.2, C129.2, C130.2, C131.2, C132.2, C133.2, C134.2, C135.2, C136.2, C201.2, C301.2, C602.2, C603.2, C604.2, C701.2, C801.2, C901.2, C1001.2, C1101.2, C1201.2, C1301.2, C1401.2, C2303.2, C2304.2, C2305.2, C2306.2, C2307.2, C2308.2, C2309.2, C2310.2, C2311.2, C2312.2, C2313.2, C2314.2, C2315.2, C2403.2, C2404.2, C2405.2, C2406.2, C2407.2, C2408.2, C2409.2, C2410.2, C2411.2, C2412.2, C2413.2, C2414.2, C2415.2, C2503.2, C2504.2, C2505.2, C2506.2, C2507.2, C2508.2, C2509.2, C2510.2, C2511.2, C2512.2, C2513.2, C2514.2, C2515.2, C2603.2, C2604.2, C2605.2, C2606.2, C2607.2, C2608.2, C2609.2, C2610.2, C2611.2, C2612.2, C2613.2, C2614.2, C2615.2, D105.2, D108.1, D109.1, D701.1, D801.1, D901.1, D1001.1, D1101.1, D1201.1, D1301.1, D1401.1, J103.1, J103.2, J104.4, J104.6, J104.8, J104.10, J104.12, J104.14, J104.16, J104.18, J104.20, J105.2, J106.4, J109.4, J110.1, J111.2, J112.2, J113.3, J113.4, J201.1, J301.1, J2302.2, J2402.2, J2502.2, J2602.2, Q401.1, Q402.1, Q501.1, Q502.1, Q1501.1, Q1601.1, Q1701.1, Q1801.1, Q1901.1, Q2001.1, Q2101.1, Q2201.1, R101.2, R102.2, R104.2, R105.1, R107.2, R116.2, R117.2, R118.2, R119.2, R120.2, R125.2, R128.2, R603.2, SW105.2, TP114.1, TP115.1, TP116.1, TP117.1, U101.16, U101.31, U101.38, U101.51, U101.61, U101.83, U101.94, U101.107, U101.120, U101.130, U102.7, U102.18, U102.21, U102.25, U102.26, U201.1, U201.2, U301.1, U301.2, U601.4, U2301.1, U2301.12, U2301.19, U2301.28, U2301.PAD, U2401.1, U2401.12, U2401.19, U2401.28, U2401.PAD, U2501.1, U2501.12, U2501.19, U2501.28, U2501.PAD, U2601.1, U2601.12, U2601.19, U2601.28, U2601.PAD
unnamed: C133.1, U102.17
unnamed: C601.2, R601.2, R603.1, U601.6
unnamed: C604.1, U601.5
unnamed: C2301.1, D2301.3, U2301.14
unnamed: C2302.1, D2301.2
unnamed: C2302.2, U2301.13
unnamed: C2315.1, R2306.2, R2307.2, U2301.7
unnamed: C2401.1, D2401.3, U2401.14
unnamed: C2402.1, D2401.2
unnamed: C2402.2, U2401.13
unnamed: C2415.1, R2406.2, R2407.2, U2401.7
unnamed: C2501.1, D2501.3, U2501.14
unnamed: C2502.1, D2501.2
unnamed: C2502.2, U2501.13
unnamed: C2515.1, R2506.2, R2507.2, U2501.7
unnamed: C2601.1, D2601.3, U2601.14
unnamed: C2602.1, D2601.2
unnamed: C2602.2, U2601.13
unnamed: C2615.1, R2606.2, R2607.2, U2601.7
unnamed: D101.2, R101.1
unnamed: D102.2, R102.1
unnamed: D103.2, R104.1
unnamed: D104.2, R107.1
unnamed: D105.1, R106.1
unnamed: D106.1, R121.1
unnamed: D106.2, U102.23
unnamed: D107.1, R123.1
unnamed: D107.2, U102.22
unnamed: D2302.1, R2301.2
unnamed: D2303.1, R2303.2
unnamed: D2402.1, R2401.2
unnamed: D2403.1, R2403.2
unnamed: D2502.1, R2501.2
unnamed: D2503.1, R2503.2
unnamed: D2602.1, R2601.2
unnamed: D2603.1, R2603.2
unnamed: J104.11, R116.1
unnamed: J104.17, R117.1
unnamed: J104.19, R118.1
unnamed: J106.2, U102.16
unnamed: J106.3, U102.15
unnamed: J111.1, JP101.1
unnamed: J112.1, JP102.1
unnamed: J201.2, U201.3
unnamed: J301.2, U301.3
unnamed: J2301.1, U2301.35, U2301.36
unnamed: J2301.2, U2301.2, U2301.3
unnamed: J2301.3, U2301.17, U2301.18
unnamed: J2301.4, U2301.20, U2301.21
unnamed: J2302.1, R2307.1
unnamed: J2401.1, U2401.35, U2401.36
unnamed: J2401.2, U2401.2, U2401.3
unnamed: J2401.3, U2401.17, U2401.18
unnamed: J2401.4, U2401.20, U2401.21
unnamed: J2402.1, R2407.1
unnamed: J2501.1, U2501.35, U2501.36
unnamed: J2501.2, U2501.2, U2501.3
unnamed: J2501.3, U2501.17, U2501.18
unnamed: J2501.4, U2501.20, U2501.21
unnamed: J2502.1, R2507.1
unnamed: J2601.1, U2601.35, U2601.36
unnamed: J2601.2, U2601.2, U2601.3
unnamed: J2601.3, U2601.17, U2601.18
unnamed: J2601.4, U2601.20, U2601.21
unnamed: J2602.1, R2607.1
unnamed: Q101.2, R103.2
unnamed: Q101.3, R106.2
unnamed: Q401.2, Q402.3, R402.2
unnamed: Q402.2, R403.1
unnamed: Q501.2, Q502.3, R502.2
unnamed: Q502.2, R503.1
unnamed: Q1501.2, R1501.2
unnamed: Q1601.2, R1601.2
unnamed: Q1701.2, R1701.2
unnamed: Q1801.2, R1801.2
unnamed: Q1901.2, R1901.2
unnamed: Q2001.2, R2001.2
unnamed: Q2101.2, R2101.2
unnamed: Q2201.2, R2201.2
unnamed: R124.1, U102.14
unnamed: R126.2, R127.1
unnamed: R127.3, R128.1
unnamed: R602.2, U601.2

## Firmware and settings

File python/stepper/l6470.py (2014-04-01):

#!/usr/bin/env python3
# -*- coding: utf-8 -*-

from collections import OrderedDict

import signal

class DelayedKeyboardInterrupt(object):
	def __enter__(self):
		self.signal_received = False
		self.old_handler = signal.getsignal(signal.SIGINT)
		signal.signal(signal.SIGINT, self.handler)
	
	def handler(self, signal, frame):
		self.signal_received = (signal, frame)
		print('SIGINT received. Delaying KeyboardInterrupt.')
	
	def __exit__(self, type, value, traceback):
		signal.signal(signal.SIGINT, self.old_handler)
		if self.signal_received:
			self.old_handler(*self.signal_received)

def without_interruptions(function):
	def wrapper(*args):
		with DelayedKeyboardInterrupt():
			return function(*args)
	return wrapper

def split_bytes(value,num_bytes=None):
	"""Given a long int it'll split it in bytes."""
	s=[]
	while 1:
		s.append(value%256)
		value//=256
		
		if num_bytes is None:
			if value==0:
				break
		else:
			num_bytes-=1
			if num_bytes==0:
				break
	return reversed(s)

class StepperBaseException(BaseException):
	"""All exceptions related to the stepper."""
	status_bits=OrderedDict()
	
	def __init__(self,motor_driver,doc=None,other_exceptions=()):
		self.motor_driver=motor_driver
		if doc is not None:
			self.__doc__=doc
		self.other_exceptions=other_exceptions
	
	@classmethod
	def register_status_bit(cls,bit_name):
		"""Decorator to associate child exception with bits from the status register."""
		def wrapper(child_exception):
			cls.status_bits[bit_name]=child_exception
			return child_exception
		return wrapper
	
	def __repr__(self):
		if len(self.other_exceptions)==0:
			others=""
		else:
			others=",%r" % (self.other_exceptions)
		return "%s(%r,%r%s)" % (self.__class__.__name__,self.motor_driver,self.__doc__,others)
	def __str__(self):
		if len(self.other_exceptions)==0:
			others=""
		else:
			others="\nOthers: %r" % (self.other_exceptions)
		return "%s on %r%s" % (self.__doc__,self.motor_driver,others)

class StepperException(StepperBaseException,Exception):
	"""Anything that's not normal behavoir."""

@StepperBaseException.register_status_bit("OCD")
class OCD(StepperException):
	"""Overcurrent"""
	pass
@StepperBaseException.register_status_bit("TH_SD")
class TH_SD(StepperException):
	"""Thermal shutdown"""
	pass
@StepperBaseException.register_status_bit("TH_WRN")
class TH_WRN(StepperException,Warning):
	"""Thermal warning"""
	pass
@StepperBaseException.register_status_bit("UVLO")
class UVLO(StepperException):
	"""Undervoltage"""
	pass
@StepperBaseException.register_status_bit("STEP_LOSS_A")
@StepperBaseException.register_status_bit("STEP_LOSS_B")
class STEP_LOSS(StepperException):
	"""Step Loss"""
	pass
@StepperBaseException.register_status_bit("WRONG_CMD")
class WRONG_CMD(StepperException,AttributeError):
	"""Wrong command"""
	pass
@StepperBaseException.register_status_bit("NOTPERF_CMD")
class NOTPERF_CMD(StepperException,ValueError):
	"""Can't perform command(perhaps wrong arguments or already in motion)"""
	pass
@StepperBaseException.register_status_bit("SW_EVN")
class SW_EVN(StepperBaseException):
	"""Limit switch event"""
	pass

class Stepper(object):
	_registers={
		0x01: 'ABS_POS',
		0x02: 'EL_POS',
		0x03: 'MARK',
		0x04: 'SPEED',
		0x05: 'ACC',
		0x06: 'DEC',
		0x07: 'MAX_SPEED',
		0x08: 'MIN_SPEED',
		0x15: 'FS_SPD',
		0x09: 'KVAL_HOLD',
		0x0A: 'KVAL_RUN',
		0x0B: 'KVAL_ACC',
		0x0C: 'KVAL_DEC',
		0x0D: 'INT_SPEED',
		0x0E: 'ST_SLP',
		0x0F: 'FN_SLP_ACC',
		0x10: 'FN_SLP_DEC',
		0x11: 'K_THERM',
		0x12: 'ADC_OUT',
		0x13: 'OCD_TH',
		0x14: 'STALL_TH',
		0x16: 'STEP_MODE',
		0x17: 'ALARM_EN',
		0x18: 'CONFIG',
		0x19: 'STATUS',
	}
	
	_register_lens={
		0x01: 22,
		0x02: 9,
		0x03: 22,
		0x04: 20,
		0x05: 12,
		0x06: 12,
		0x07: 10,
		0x08: 13,
		0x15: 10,
		0x09: 8,
		0x0A: 8,
		0x0B: 8,
		0x0C: 8,
		0x0D: 14,
		0x0E: 8,
		0x0F: 8,
		0x10: 8,
		0x11: 4,
		0x12: 5,
		0x13: 4,
		0x14: 7,
		0x16: 8,
		0x17: 8,
		0x18: 16,
		0x19: 16,
	}
	
	@classmethod
	def _register_info(self,register):
		"""@returns id,name and length no matter what type of argument it recieved(name or id)"""
		reg_id=None
		if not type(register)==int:
			register=register.upper()
			for key,value in self._registers.items():
				if value==register:
					reg_id=key
					break
			else:
				raise ValueError("No such register %s." % register)
		
		reg_name=self._registers[reg_id]
		reg_len=self._register_lens[reg_id]
		
		return reg_id, reg_name, reg_len

	_commands={
		'NOP': 0x00,
		'SET_PARAM': 0x00,
		'GET_PARAM': 0x20,
		'RUN': 0x50,
		'STEP_CLOCK': 0x58,
		'MOVE': 0x40,
		'GOTO': 0x60,
		'GOTO_DIR': 0x68,
		'GO_UNTIL': 0x82,
		'RELEASE_SW': 0x92,
		'GO_HOME': 0x70,
		'GO_MARK': 0x78,
		'RESET_POS': 0xD8,
		'RESET_DEVICE': 0xC0,
		'SOFT_STOP': 0xB0,
		'HARD_STOP': 0xB8,
		'SOFT_HIZ': 0xA0,
		'HARD_HIZ': 0xA8,
		'GET_STATUS': 0xD0,
	}
	
	def __init__(self,spi):
		self.spi=spi
		self.reset()
		try:
			self.check_errors()
		except UVLO:
			"""It's normal to have this when it boots the first time."""
			pass
	
	@without_interruptions
	def nop(self,count=5):
		for i in range(count):
			self.spi.xfer(self._commands["NOP"])
	
	@without_interruptions
	def __getitem__(self,reg):
		"""Gets register"""
		reg_id,reg_name,reg_len=self._register_info(reg)
		
		self.spi.xfer(self._commands["GET_PARAM"]+reg_id)
		
		value=0
		reg_len_bytes=(reg_len-1)//8+1
		for i in reversed(range(reg_len_bytes)):
			byte=self.spi.xfer(0)
			value+=byte*(256**i)
		
		if reg_name=="ABS_POS":
			half_range=2**(reg_len-1)
			full_range=half_range*2
			if value>=half_range:
				value-=full_range
		
		return value
	
	@without_interruptions
	def __setitem__(self,reg,value):
		"""Sets register"""
		reg_id,reg_name,reg_len=self._register_info(reg)
		
		self.spi.xfer(self._commands["SET_PARAM"]+reg_id)
		
		mask=(2**reg_len)-1
		value&=mask
		
		reg_len_bytes=(reg_len-1)//8+1
		for b in split_bytes(value,reg_len_bytes):
			self.spi.xfer(b)
	
	@without_interruptions
	def run(self,speed):
		"""Run at constant speed."""
		direction=speed>0
		self.spi.xfer(self._commands["RUN"]+direction)
		for b in split_bytes(abs(speed),num_bytes=3):
			self.spi.xfer(b)
	
	@without_interruptions
	def step_clock(self,direction=False):
		"""Switch into the step clock mode(direction from the pin)."""
		self.spi.xfer(self._commands["STEP_CLOCK"]+forward)
	
	@without_interruptions
	def move(self,steps):
		"""Relative move."""
		direction=steps>0
		self.spi.xfer(self._commands["MOVE"]+direction)
		for b in split_bytes(abs(steps),num_bytes=3):
			self.spi.xfer(b)
	
	@without_interruptions
	def goto(self,position):
		"""Absolute move to position though the shortest path(could wrap around)."""
		self.spi.xfer(self._commands["GOTO"])
		for b in split_bytes(position%(2**22),num_bytes=3):
			self.spi.xfer(b)
	
	@without_interruptions
	def goto_dir(self,position,direction):
		"""Absolute move to position though the shortest path, by explicitly defining a direction."""
		self.spi.xfer(self._commands["GOTO_DIR"]+direction)
		for b in split_bytes(position%(2**22),num_bytes=3):
			self.spi.xfer(b)
	
	@without_interruptions
	def go_until(self,speed,direction,mark=False):
		"""Go with a specific speed and direction until the switch is pressed.
		If mark==True then the current position will be copied to the MARK register, otherwise the home position will be reset."""
		self.spi.xfer(self._commands["GO_UNTIL"]+(mark<<3)+direction)
		for b in split_bytes(abs(speed),num_bytes=3):
			self.spi.xfer(b)
	
	@without_interruptions
	def release_sw(self,direction,mark=False):
		"""Go with the minimum speed and direction until the switch is released.
		If mark==True then the current position will be copied to the MARK register, otherwise the home position will be reset."""
		self.spi.xfer(self._commands["RELEASE_SW"]+(mark<<3)+direction)
	
	@without_interruptions
	def go_home(self):
		"""Go to ABS_POS==0 through the shortest path."""
		self.spi.xfer(self._commands["GO_HOME"])
	@without_interruptions
	def go_mark(self):
		"""Go to ABS_POS==MARK through the shortest path."""
		self.spi.xfer(self._commands["GO_MARK"])
	
	@without_interruptions
	def reset_pos(self):
		"""Set ABS_POS=0."""
		self.spi.xfer(self._commands["RESET_POS"])
	
	@without_interruptions
	def reset(self,unsafe=False):
		"""Resets the device to default state."""
		
		if not unsafe:
			#make sure it's not moving
			self.soft_hiz()
			while self.status["BUSY"]:
				pass
		
		self.spi.xfer(self._commands["RESET_DEVICE"])
	
	@without_interruptions
	def soft_stop(self):
		"""Deaccelerate to a hold."""
		self.spi.xfer(self._commands["SOFT_STOP"])
	@without_interruptions
	def hard_stop(self):
		"""Instantly stop to a hold."""
		self.spi.xfer(self._commands["HARD_STOP"])
	@without_interruptions
	def soft_hiz(self):
		"""Deaccelerate to a HiZ."""
		self.spi.xfer(self._commands["SOFT_HIZ"])
	@without_interruptions
	def hard_hiz(self):
		"""Instantly stop to a HiZ."""
		self.spi.xfer(self._commands["HARD_HIZ"])
	
	@staticmethod
	def _parse_status(value):
		def test_bit(bit_id):
			return bool(value&(1<<bit_id))
		return {
			"SCK_MOD": test_bit(15), #Step Clock Mode
			"STEP_LOSS_B": not test_bit(14), #Skipped step
			"STEP_LOSS_A": not test_bit(13), #Skipped step
			"OCD": not test_bit(12), #Overcurrent
			"TH_SD": not test_bit(11), #Thermal shutdown
			"TH_WRN": not test_bit(10), #Thermal warning point
			"UVLO": not test_bit(9), #Undervoltage/powerup
			"WRONG_CMD": test_bit(8), #Cannot find command
			"NOTPERF_CMD": test_bit(7), #Argument error
			"MOT_STATUS": ["Stopped","Accelerating","Deccelerating","Constant Speed"][(value>>5)&0b11], #Motion mode
			"DIR": test_bit(4), #Forward direction
			"SW_EVN": test_bit(3), #Switch turn on event
			"SW_F": test_bit(2), #Switch state(high=closed)
			"BUSY": not test_bit(1),
			"HiZ": test_bit(0),
		}
	
	@without_interruptions
	def get_status(self):
		"""Returns the status dict, but also clears all the latchable stuff
		(UVLO, TH_WRN, TH_SD, OCD, STEP_LOSS_A, STEP_LOSS_B, NOTPERF_CMD, WRONG_CMD and SW_EVN)."""
		self.spi.xfer(self._commands["GET_STATUS"])
		value=self.spi.xfer(0)*256+self.spi.xfer(0)
		return self._parse_status(value)
	@property
	def status(self):
		"""Returns fancy status dict."""
		return self._parse_status(self["status"])
	
	def check_errors(self,status=None):
		"""Checks the status and raises exceptions if needed."""
		if status is None:
			status=self.get_status()
		exceptions=[]
		for possible_error,possible_exception in StepperException.status_bits.items():
			if status[possible_error]:
				exceptions.append(possible_exception)
		if len(exceptions)==0:
			return
		else:
			raise exceptions[0](self,other_exceptions=[other(self) for other in exceptions[1:]])
	
	def wait(self):
		"""Blocks while busy."""
		while True:
			status=self.get_status()
			try:
				self.check_errors(status)
			except STEP_LOSS:
				pass
			except Exception as e:
				raise
			if not status["BUSY"]:
				break
	
	def calibrate(self,speed=5000):
		try:
			self.go_until(speed,0)
			self.wait()
		except SW_EVN:
			pass
		
		try:
			self.release_sw(1)
			self.wait()
		except SW_EVN:
			pass
	
	def __repr__(self):
		return "L6460(%r)" % (self.spi,)

if __name__=="__main__":
	import pirate430
	spi_device=pirate430.SPIDevice(pirate430.SPI(),cs=2)
	
	s=Stepper(spi_device)
	s["config"]=0b0001111010001000 #lower pwm frequency
	s["acc"]=s["dec"]=1000
	s["kval_acc"]=s["kval_dec"]=100
	s["kval_run"]=50
	s["kval_hold"]=30
	s["step_mode"]=7 #128 microstepping
	s["int_speed"]=0
	s["st_slp"]=0
	s["fn_slp_acc"]=0
	s["fn_slp_dec"]=0
	s["fs_spd"]=1000
	s["max_speed"]=1048575//1024//1
	s["ocd_th"]=0b1010 #3.75A
	
	def zigzag():
		try:
			while(1):
				s.move(10000*100)
				s.wait()
				
				s.move(-(10000+128//8)*100)
				s.wait()
				
				s.check_errors()
		except:
			s.nop()
			raise
	zigzag()

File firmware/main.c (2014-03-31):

/*
 * TR2 Robot Controller Application
 */

#include <stdint.h>
#include <stdbool.h>

#include "SystemResetClock.h"
#include "SystemInterrupts.h"

#include "TrProtocol.h"
#include "TrWs2812.h"


int main(void)
{
    SystemIrqEnable();
    
    TrInit();

    while(1)
    {
        TrParseCommand();
    }
    
    return 0;
}

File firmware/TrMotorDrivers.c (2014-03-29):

/*
 * Tr2 Board Motor Drivers
 */

#include "TrMotorDrivers.h"

/* Initialization *************************************************************/

void TrMotorDriversInit(void)
{
    // Enable chip select lines
    SystemClockEnabled.GpioG = true;

    // As outputs
    SystemGpioG.Mode.P4 = SystemGpioMode_Output;
    SystemGpioG.Mode.P5 = SystemGpioMode_Output;
    SystemGpioG.Mode.P6 = SystemGpioMode_Output;
    SystemGpioG.Mode.P7 = SystemGpioMode_Output;
    
    // Initial state is high
    SystemGpioG.Set.P4 = true;
    SystemGpioG.Set.P5 = true;
    SystemGpioG.Set.P6 = true;
    SystemGpioG.Set.P7 = true;

    // Spi Pins
    SystemClockEnabled.GpioB = true;
    SystemClockEnabled.GpioC = true;
    
    // As alternate functions
    SystemGpioB.Mode.P10 = SystemGpioMode_Alternate;
    SystemGpioC.Mode.P2 = SystemGpioMode_Alternate;
    SystemGpioC.Mode.P3 = SystemGpioMode_Alternate;
    SystemGpioB.Function.P10 = 5;
    SystemGpioC.Function.P2 = 5;
    SystemGpioC.Function.P3 = 5;
    
    // Spi Module
    SystemClockEnabled.SPI2 = true;
    SystemSpi2.Config.SlaveManageEnable = true;
    SystemSpi2.Config.InternalSelect = true;
    SystemSpi2.Config.DeviceMode = SystemSpiDeviceMode_Master;
    SystemSpi2.Config.Prescaler = SystemSpiPrescaler_128;
    SystemSpi2.Config.ClockPhase = SystemSpiClockPhase_Second;
    SystemSpi2.Config.ClockIdle = SystemSpiClockIdle_High;
    SystemSpi2.Config.Enabled = true;
}

bool TrMotorDriversValidateNum(uint32_t driverNum)
{
    return driverNum < MOTOR_COUNT;
}

/* Commands *******************************************************************/

bool TrMotorRawSpi(uint32_t driverNum,
    uint32_t *buf,
    uint32_t length)
{
    if(TrMotorDriversValidateNum(driverNum))
    {
        L6470RawSpi(&SystemSpi2,
            buf,
            length,
            &SystemGpioG,
            driverNum + MOTORCS_START);
        return true;
    }

    return false;
}

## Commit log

2013-10-03 Added blender model of the robot. The X angle of each of the Joints can be changed.
    [deltabot.blend]
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2013-10-05 rotated blender model so it matches the code
    [deltabot.blend]
2013-10-05 Got blender to do live inverse kinematics using our code. Changed to the right point for the circle intersect
    [deltabot.blend]
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2013-10-06 fixed forward kinematics(i had the radius wrong), blender can now do forward kinematics too
    [deltabot.blend]
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2014-01-13 it mostly works now, doesn't stop in some cases though
    [virtual.py]
2014-01-21 Created a KiCAD project
    This commit brings in a KiCAD project that is empty. I am preparing to
    build the latest version of KiCAD.
    [robot_controller.sch]
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2014-01-27 Almost finished stepper-driver schematic. Library touchups as well.
    [stepper_driver.sch]
2014-01-27 Voltage Regulator, Reset Logic
    [robot_controller.sch]
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2014-01-27 3.3V Regulator
    I have created the switching mode 3.3V regulator, capable of handling
    up to 1A.
    [3v3_regulator.sch]
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2014-01-27 Fixed airwire positions.
    [robot_controller.sch]
2014-01-27 Wired up the stepper driver blocks in the main schematic. Titled the sheets.
    [3v3_regulator.sch, robot_controller.sch, stepper_driver.sch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]
2014-01-27 Industrial Input
    I have designed an industrial input that is low-pass filtered and
    schottky diode protected against over and under voltage. This circuit
    will work for both analog and digital.
    [industrial_input.sch]
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2014-01-28 Created Industrial Output, More Datasheets
    I have created a circuit for industrial output that is back-EMF
    protected. I have added the datasheets for the transistor and diode
    used in this circuit.
    [industrial_input.sch, industrial_output.sch]
2014-01-29 Worked on the stepper motor interface.
    * Organized stepper files better(moved buspirate driver in another file).
    * Added check for the status register(with exceptions!).
    * Tried the bigger motor(no OCD problems this time!).
    [buspirate.py, l6470.py]
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2014-02-01 Robot Controller Boot Logic, Decoupling
    I have added boot logic to the main schematic that will allow us to
    boot from the serial bootloader by pressing a button on the board.
    I have added decoupling to the base MCU for analog and digital.
    [$robot_controller.sch]
2014-02-01 FTDI USB
    I have added USB connectivity to this processor via an FT232RL
    interface chip.
    [$robot_controller.sch, robot_controller.sch, stepper_driver.sch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]
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2014-02-01 FTDI Tx and Rx LEDs
    I forgot to add the Tx and Rx LEDs for the FTDI chip.
    [robot_controller.sch]
2014-02-01 SPI for Steppers and Temperature
    I cleaned up the stepper driver section of the main schematic and
    routed the high speed SPI interface over to it. I also got the second
    SPI module connected to the temperature sensors.
    [robot_controller.sch, stepper_driver.sch, temperature.sch]
2014-02-01 Added JTAG Debug Port
    I have added the JTAG debug port. The JTAG lines are internally pulled
    high by the MCU to avoid an unknown JTAG state.
    [robot_controller.sch]
2014-02-02 Fixed "Missing NXP" Library
    I borrowed the JTAG symbol from the ARM NXP library and copied it into
    our "components" library but forgot to remove the reference to NXP.
2014-02-02 switched to pirate430 driver, added some safety when resetting
    [l6470.py]
2014-02-02 Created a WS2812 LED Data Buffer
    This circuit buffers the WS2812 data, increasing drive strength. It
    also protects against accidental connection to a supply rail.
    [ws2812_buffer.sch]
2014-02-02 Removed double schottky
    The double schottky wouldn't do much in this case. I have removed it.
    [ws2812_buffer.sch]
2014-02-03 Added the LED data lines and connector
    I have added the LED data lines to the main schematic along with the
    connector.
    [robot_controller.sch, stepper_driver.sch, temperature.sch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]
2014-02-06 Schematic Additions
    * UEXT
    * AUX UART
    * Regulator
    * Fixed hirearchical label directions
    [3v3_regulator.sch, robot_controller.sch, stepper_driver.sch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]
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2014-02-06 Replaces the 2 diodes with a double shottky diode for the steppers.
    [stepper_driver.sch]
2014-02-06 Added 24V connector and fixed a few things on the 24V rail.
    [robot_controller.sch, stepper_driver.sch]
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2014-02-07 Datasheets, WS2812 Driver
    I have added datasheets for the LEDs, the discovery board and power
    transistors. I have designed a WS2812 data buffer circuit.
    [robot_controller.sch, stepper_driver.sch, temperature.sch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]
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2014-02-08 Non-interactive flash programming!
    This commit brings in a program target for OpenOCD that loads code
    without firing up a GDB session.
    [stm32f4program.cfg]
2014-02-08 Simplistic Reset/Clock, Gpio Drivers
    This commit brings in the foundation for a driver for the reset/clock
    logic and gpio peripherals.
    [main.c]
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2014-02-09 Bug in GPIO, Sample Input Program
    There was a bug in the GPIO driver. One of my unions was declared as a
    struct and I accidentally skipped a register. Everything was working
    fine but I was missing the speed register.
    [main.c]
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2014-02-09 Anonymous Structs!
    I'm not sure why I didn't think of this sooner, but I have switched
    everything to anonymous structs.
    This allows for more direct access to the Pins/Port concept rather than
    indirecting through Mode.Pins.P0. You can go directly to the pin or port
    as in Mode.P0. or Mode.P0.
    [SystemSpi.h, main.c]
2014-02-10 Reiner Documentation, Industrial GPIO, Driver Fix
    I added documentation for the meaning of Reiner's board pins. I have
    finished implemented the industrial inputs on the schematic and partial
    industrial outputs. I have added some capacitors to the motor drivers.
    [3v3_regulator.sch, industrial_input.sch, industrial_output.sch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]
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2014-02-10 Decoupled the Stepper Driver, Main Schematic
    The stepper driver is now decoupled according to the demo board
    schematic.
    The main schematic is nearly complete minus a couple of minor issues.
    [industrial_output.sch, robot_controller.sch, stepper_driver.sch]
2014-02-12 Made a more efficient use of the MCU hardware peripherals.
    See https://github.com/amstan/tr2/wiki/MCU-Pheripherals-Allocation for more details.
    * Added STCK pins to individual timers so the MCU can control the steppers step by step.
    * Worried about the Industrial GPIOs to be connected to timers(most of them)
    * Swapped some SPIs and UARTs to achieve better speeds
    * Cleaned up schematic
    [industrial_input.sch, industrial_output.sch, robot_controller.sch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]
2014-02-13 Fixed sheet names
    [robot_controller.sch]
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2014-02-15 User LEDs and Switches
    I have added User LEDs and Switches to the robot controller board.
    [robot_controller.sch]
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2014-02-15 Fixed error with saving footprints.
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2014-02-16 Comprehensive Schematic Review, Power LED
    The schematic was reviewed. Components were selected. Fixed minor bugs
    encountered during review. Debounced switches.
    Added a power LED with a transistor that causes it to be normally-on.
    [industrial_input.sch, industrial_output.sch, robot_controller.sch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]
2014-02-16 Fixed ERC Errors. Annotated all components.
    [3v3_regulator.sch, industrial_input.sch, industrial_output.sch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]
2014-02-16 Fixed a couple of errors in the schematic.
    [industrial_input.sch, industrial_output.sch, robot_controller.sch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]
2014-02-16 GDB Init, Interrupts, Start Code in C, UART Start
    * Created a GDB init file that automatically connects to OpenOCD
    and reset/halts the processor
    * Wrote a header file for the NVIC in the M4
    * Changed start code to C, found some bugs in the asm version (I suck
    at assembly).
    * Started working on an interrupt driven UART driver
    * Based on the SystemRingBuffer struct.
    [crt0.c, main.c]
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2014-02-17 Thread Safety Bug Fixes
    I have made the driver thread-safe by disabling Tx/Rx interrupts when
    accessing the Tx and Rx buffers.
    [main.c]
2014-02-17 Industrial Output Ground, Associated Footprints
    * Fixed an issue with the industrial output ground, it is now on the
    power ground rail.
    * Associated most of the footprints, need to make a few.
    [industrial_output.sch, robot_controller.sch]
2014-02-17 Resolved issues while associating footprints.
    [3v3_regulator.sch, industrial_input.sch, industrial_output.sch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]
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2014-02-17 Digikey Number + Link
    Added a digikey part number and link to all components.
    [3v3_regulator.sch, industrial_input.sch, industrial_output.sch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]
2014-02-17 Created Stepper Driver Footprint, FreeCAD Test
    I created a stepper driver footprint.
    I also experimented with FreeCAD in the models folder. It might be nice
    to create 3D models of our components.
    [9993920000.fcstd]
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2014-02-18 Fixed an issue with the CONN_STEPPER
    [stepper_driver.sch]
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2014-03-01 Worked on a way to route the 5 wires underneath the capacitor.
    [robot_controller.kicad_pcb]
2014-03-01 Stepper Driver layout almost done, updated some of the footprints based on Andrew's work.
    [robot_controller.kicad_pcb]
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2014-03-01 Started layout of a few other 'modules'. More work on the stepper drivers. Used more Andrew footprints.
    [robot_controller.kicad_pcb]
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2014-03-02 Trimmer Potentiometer Fix, Pushbutton Created
    Fixed an issue with the trim potentiometer and created a pushbutton
    footprint.
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2014-03-02 SOLDER_BRIDGE Footprint
    Added the SOLDER_BRIDGE footprint to our component library. I added it
    to the layout as well.
    [robot_controller.kicad_pcb]
2014-03-02 SHROUDED_10 and SHROUDED_20 Footprints
    Created two footprints for the UEXT and JTAG connectors.
    [robot_controller.kicad_pcb]
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2014-03-02 More work on the stepper motors. Organized a lot of labels. Preparing for copying stepper motors.
    [robot_controller.kicad_pcb, stepper_driver.sch]
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2014-03-08 Fixed Jtag connector. Did some more global layout.
    [robot_controller.kicad_pcb, robot_controller.sch]
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2014-03-10 Fixed Main Power Footprint
    Updated the footprint on the PCB layout and the track connected to it.
    [robot_controller.kicad_pcb]
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2014-03-10 Fixed hole size on shrouded connectors
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2014-03-10 Increased the size of the PFM heatsink.
    Solder can be applied from the top now, hopefully avoiding an oven.
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2014-03-10 Fixed DRC with the new part changes
    [robot_controller.kicad_pcb]
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2014-03-11 PentaLogix DRC Fixes
    Moved some traces inside of the board outline.
    [robot_controller.kicad_pcb]
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2014-03-11 Fixed annular ring errors
    [robot_controller.kicad_pcb]
2014-03-11 Fixed holes
    [robot_controller.kicad_pcb]
2014-03-11 Removed soldermask from the bottom side of the board underneath the drivers.
    [robot_controller.kicad_pcb]
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2014-03-27 Stepper Driver Improvements
    Added better exception handling.
    It now includes descriptions for the exceptions and __str__ and __repr__ methods.
    Added a wait method that blocks until it's not busy.
    Fixed issue with negative goto.
    [l6470.py]
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2014-03-27 Having difficulties with the dimensions of the robot, it i can't seem to get a straight line.
    [test_kinematics.blend]
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2014-03-29 Fixed a function declaration, PLL Register
    [TrProtocol.c]
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
